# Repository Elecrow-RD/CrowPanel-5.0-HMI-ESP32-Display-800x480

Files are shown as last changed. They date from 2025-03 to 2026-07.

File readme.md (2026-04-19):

### 1, Product picture

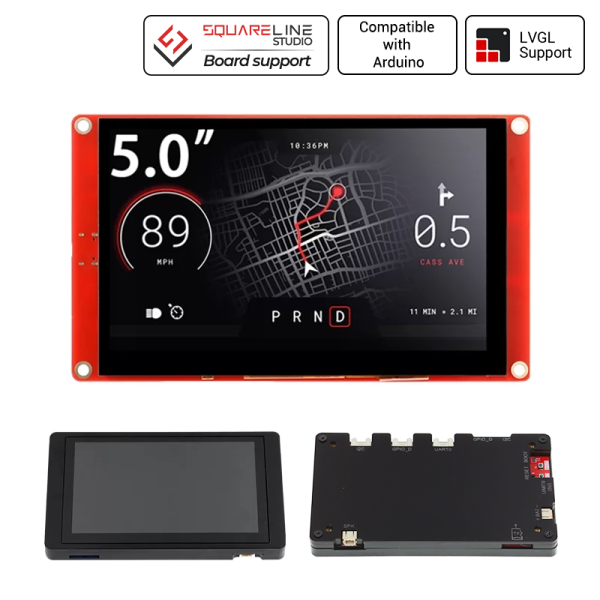
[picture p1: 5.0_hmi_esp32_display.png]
5.0_hmi_esp32_display


### 2, Product version number

| | Hardware | Software | Remark |
| ---- | --- | --- | --- |
| 1 | V1.0 | V1.0 | old |
| 1 | V2.0 | V2.0 | old |
| 1 | V3.0 | V3.0 | latest |

**Version 2.0** adds an automatic download feature over Version 1.0, eliminating the need to press boot+reset again before downloading the program.

**Version 3.0** adds touch timing control based on Version 2.0 to prevent touch failures. When writing programs, you need to build upon the Version 2.0 program to implement the timing control logic.

   PCA9557 Out;
  
   Out.reset();
  
  Out.setMode(IO_OUTPUT);  
  
  Out.setState(IO0, IO_LOW);
  
  Out.setState(IO1, IO_LOW);
  
  delay(20);
  
  Out.setState(IO0, IO_HIGH);
  
  delay(100);
  
  Out.setMode(IO1, IO_INPUT);

### 3, product information

- Model: 5.0 inch CrowPanel ESP32 display
- Main Processor: ESP32-S3-WROOM-1-N4R8
- Resolution: 800*480
- Touch Type: CapacitiveTouch Screen
- Display Type: TN Panel
- Screen: TFT-LCD Screen
- Display driver: ILI6122 & ILI5960
- External power supply: DC5V-2A
- Interface: 2\*UART0,2\*GPIO,2\*I2C,1\*Battery
- Button: BOOT Button and Reset Button
- Active Area: 108\*64.8mm(W\*H)
- Working Temperature: -20℃～70℃
- Storage Temperature: -30℃～80℃

### 4, Use the driver module

| Name | dependency library |
| ---- | --- |
| LVGL | lvgl/lvgl@8.3.3 |

### 5,Quick Start

##### Arduino IDE starts

1.Download the library files used by this product to the 'libraries' folder.

C:\Users\Documents\Arduino\libraries\



2.Open the Arduino IDE

arduino1

3.Open the code configuration environment and burn it



##### ESP-IDF starts

1.Right-click on an empty space in the project folder and select "Open with VS Code" to open the project.



2.In the IDF plug-in, select the port, then compile and flash



##### PlatformIO starts

1.Right-click on an empty space in the project folder and select "Open with VS Code" to open the project.



2.In the PlatformIO plug-in, select the port, then compile and flash

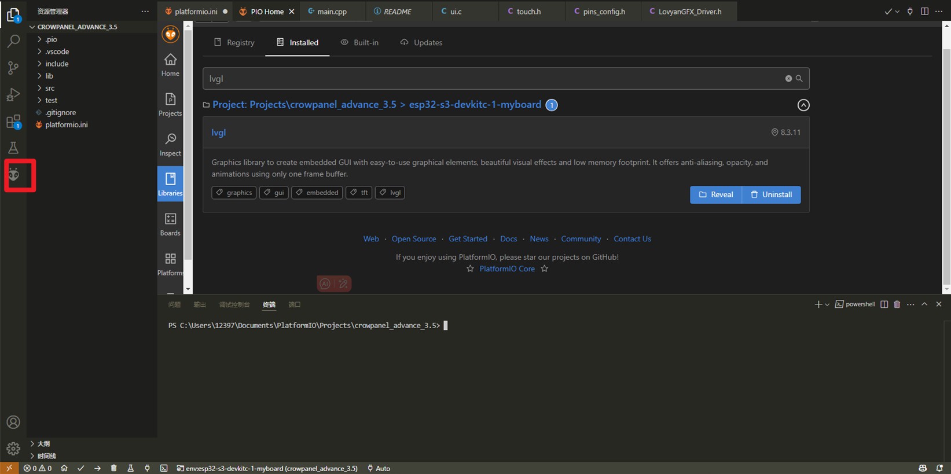
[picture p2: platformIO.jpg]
platformIO


##### Micropython starts

1,Right-click on an empty space in the project folder and select "Thonny" to open the project.

thonny

2,In thonny software, select the master and port, then run the program

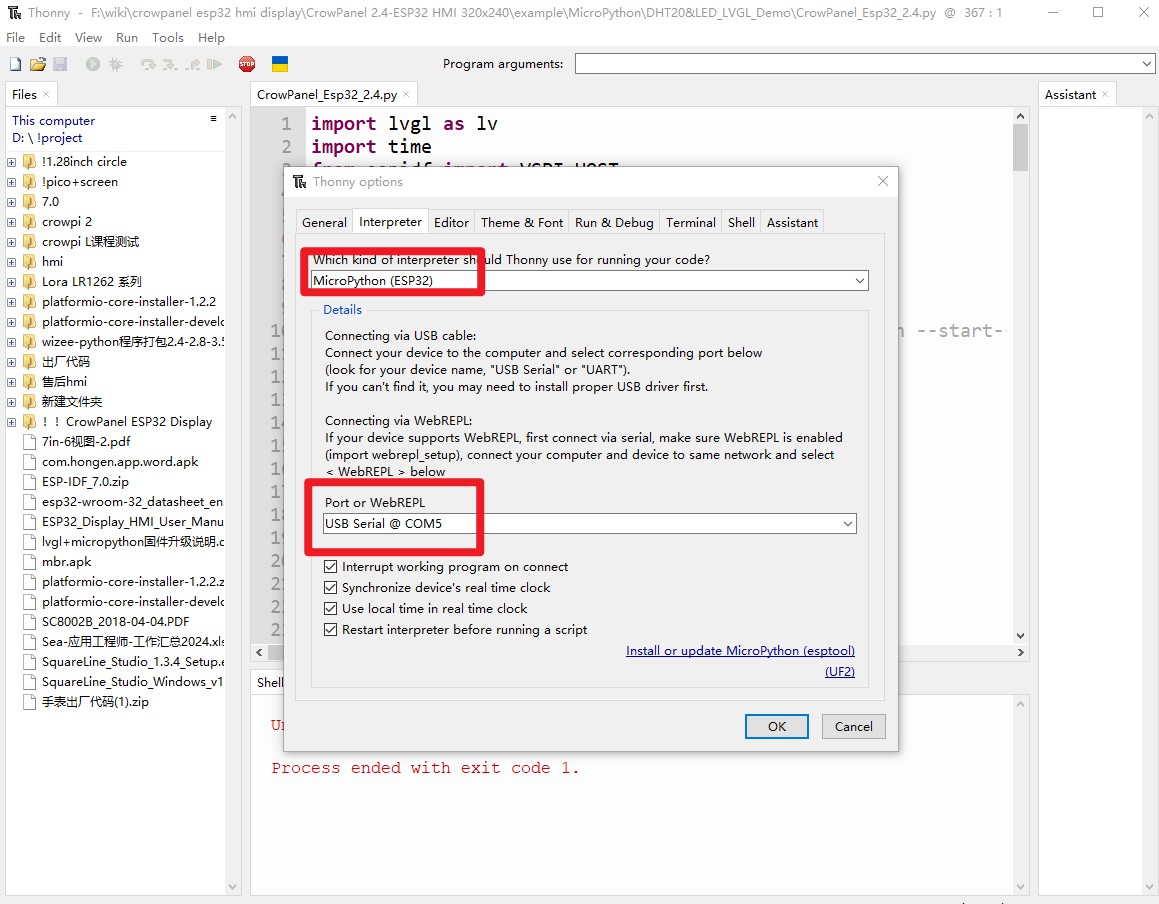
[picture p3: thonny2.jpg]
thonny2


### 6,Folder structure.

|--3D file： Contains 3D model files (.stp) for the hardware. These files can be used for visualization, enclosure design, or integration into CAD software.

|--Datasheet: Includes datasheets for components used in the project, providing detailed specifications, electrical characteristics, and pin configurations.

|--Eagle_SCH&PCB: Contains **Eagle CAD** schematic (`.sch`) and PCB layout (`.brd`) files. These are used for circuit design and PCB manufacturing.

|--example: Provides example code and projects to demonstrate how to use the hardware and libraries. These examples help users get started quickly.

|--factory_firmware: Stores pre-compiled factory firmware that can be directly flashed onto the device. This ensures the device runs the default functionality.

|--factory_sourcecode: Contains the source code for the factory firmware, allowing users to modify and rebuild the firmware as needed.

### 7,Pin definition

class LGFX : public lgfx::LGFX_Device
{
public:

  lgfx::Bus_RGB     _bus_instance;
  lgfx::Panel_RGB   _panel_instance;

  LGFX(void)
  {

    {
      auto cfg = _bus_instance.config();
      cfg.panel = &_panel_instance;
    
      cfg.pin_d0  = GPIO_NUM_8; // B0
      cfg.pin_d1  = GPIO_NUM_3;  // B1
      cfg.pin_d2  = GPIO_NUM_46;  // B2
      cfg.pin_d3  = GPIO_NUM_9;  // B3
      cfg.pin_d4  = GPIO_NUM_1;  // B4
    
      cfg.pin_d5  = GPIO_NUM_5;  // G0
      cfg.pin_d6  = GPIO_NUM_6; // G1
      cfg.pin_d7  = GPIO_NUM_7;  // G2
      cfg.pin_d8  = GPIO_NUM_15;  // G3
      cfg.pin_d9  = GPIO_NUM_16; // G4
      cfg.pin_d10 = GPIO_NUM_4;  // G5
    
      cfg.pin_d11 = GPIO_NUM_45; // R0
      cfg.pin_d12 = GPIO_NUM_48; // R1
      cfg.pin_d13 = GPIO_NUM_47; // R2
      cfg.pin_d14 = GPIO_NUM_21; // R3
      cfg.pin_d15 = GPIO_NUM_14; // R4
    
      cfg.pin_henable = GPIO_NUM_40;
      cfg.pin_vsync   = GPIO_NUM_41;
      cfg.pin_hsync   = GPIO_NUM_39;
      cfg.pin_pclk    = GPIO_NUM_0;
      cfg.freq_write  = 15000000;
    
      cfg.hsync_polarity    = 0;
      cfg.hsync_front_porch = 8;
      cfg.hsync_pulse_width = 4;
      cfg.hsync_back_porch  = 43;
    
      cfg.vsync_polarity    = 0;
      cfg.vsync_front_porch = 8;
      cfg.vsync_pulse_width = 4;
      cfg.vsync_back_porch  = 12;
    
      cfg.pclk_active_neg   = 1;
      cfg.de_idle_high      = 0;
      cfg.pclk_idle_high    = 0;
    
      _bus_instance.config(cfg);
    }
            {
      auto cfg = _panel_instance.config();
      cfg.memory_width  = 800;
      cfg.memory_height = 480;
      cfg.panel_width  = 800;
      cfg.panel_height = 480;
      cfg.offset_x = 0;
      cfg.offset_y = 0;
      _panel_instance.config(cfg);
    }
    _panel_instance.setBus(&_bus_instance);
    setPanel(&_panel_instance);

  }
};

\#define TOUCH_GT911_SCL 20//20 

#define TOUCH_GT911_SDA 19//19

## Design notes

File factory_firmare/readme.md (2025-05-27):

# How to install the factory demo firmware with flash download tool?

#### 1.Preparation:

- USB C cable
- Laptop/PC
- Crowpanel Advance HMI ESP32 AI Display
- Flash download tool

Check whether the materials on the PCBA board are defective. Such as less material, false welding, tin and other bad phenomena.

#### 2.Flash the firmware 

##### Step1 Connect the ESP32 display to the laptop/PC with USB-C cable. The power indicator will light up.

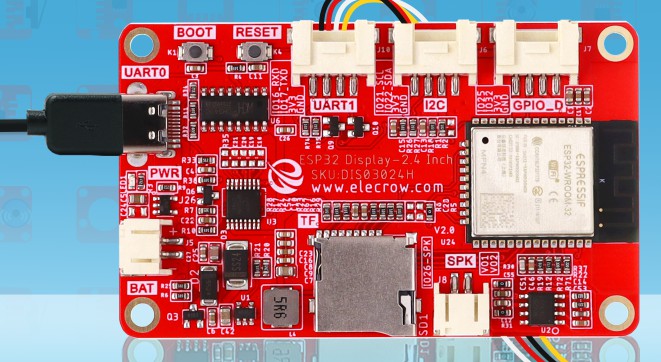
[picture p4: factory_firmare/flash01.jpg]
flash01


##### Step2 Open the flash download tool. 

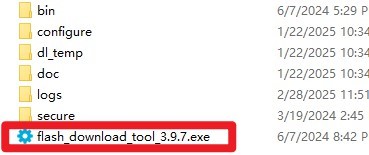
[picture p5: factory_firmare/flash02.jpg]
flash02


For the  Crowpanel Advance HMI ESP32 AI Display, the chip select ESP32-S3:

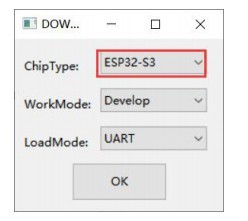
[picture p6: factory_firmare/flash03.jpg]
flash03


##### Step3

①Choose the firmware files;

flash0

②Enter the address: 

boot_app0.bin------0xe000

xxxx.ino.bin--------0x10000

xxxx.ino.bootloader.bin------0x0

xxxx.ino.partitions.bin-------0x8000

③Check the firmware files;

④Select the correct port number;

⑤Click “Start” to download

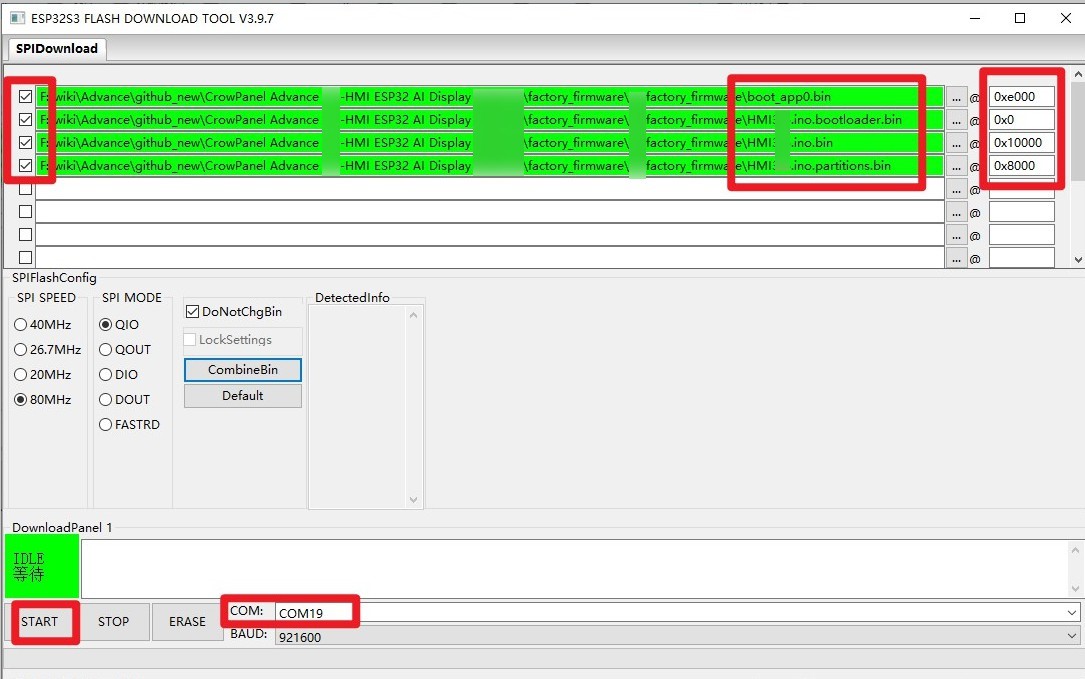
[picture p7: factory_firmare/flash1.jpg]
flash1


### Note: If it is v1.0 version, before downloading firmware or program, you need to press the boot button, then short press the reset button, and then release the boot button to enter the burn mode. If it is v2.0 or above, this step is not needed, it will automatically enter into burn mode.

##### Step5 After the download is complete, blue FINISH will be displayed, and the progress bar at the bottom shows that it has come to an end.

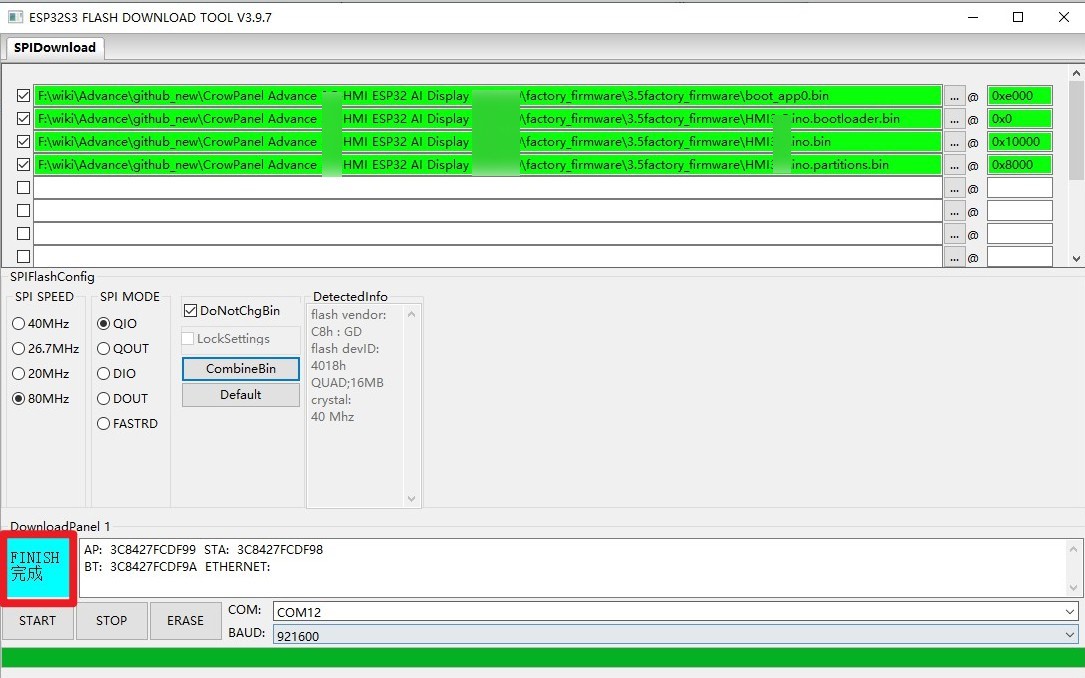
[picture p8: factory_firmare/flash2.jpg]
flash2


##### Step6 Press the reset button to show the demo.

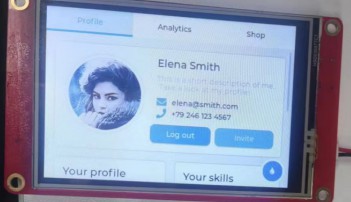
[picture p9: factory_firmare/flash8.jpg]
flash8


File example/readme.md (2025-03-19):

**Arduino**: This folder contains sample programs for the Arduino platform, which is known for its ease of use and versatility in creating interactive electronic projects.

#### NOTE!!!:When running this program , you need to download the officially provided libraries and place them in the libraries of arduino. esp32 version needs to be 2.0.14/2.0.15. the version of the libraries is the same as the officially provided version.

Link to the corresponding course wiki:https://www.elecrow.com/wiki/ESP32_Display_5.0-inch_HMI_Arduino_Tutorial.html

Video Tutorial Links：https://www.youtube.com/watch?v=x4LrIeEJTls&t=2s

**ESP_IDF**: This directory holds example code for the Espressif IoT Development Framework (ESP-IDF), designed for developing applications on ESP32 and ESP8266 microcontrollers.

Link to the corresponding course wiki:https://www.elecrow.com/wiki/CrowPanel-ESP32-5.0-inch-with-ESP-IDF.html

**Esphome**: Here you'll find sample programs for Esphome, a firmware framework that simplifies the process of creating smart home devices using ESP8266/ESP32 chips.

Link to the corresponding course wiki:https://www.elecrow.com/wiki/CrowPanel_ESP32_5.0-inch_with_ESPHome.html

**MicroPython**: This section includes examples for MicroPython, a lean and efficient implementation of the Python programming language that can run on microcontrollers.

Link to the corresponding course wiki:https://www.elecrow.com/wiki/5.0-inch_ESP32_Display_MicroPython_Tutorial.html

**PlatformIO**: This folder contains sample projects for PlatformIO, an open-source ecosystem that streamlines the development process across various embedded platforms by providing a consistent environment for coding, compiling, and uploading firmware.:

Link to the corresponding course wiki:https://www.elecrow.com/wiki/5-inch-esp32-dispaly-platformio-tutorial.html

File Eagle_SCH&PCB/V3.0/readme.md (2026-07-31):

# CrowPanel ESP32 Display 5.0-inch V3.0 Product Hardware Driver Guide

| Item | Details |
|---|---|
| Document Version | V1.0 |
| Date | 2026-07-29 |
| Author | OpenAI Codex (compiled from project materials) |
| Applicable Hardware | CrowPanel ESP32 Display 5.0-inch V3.0 |
| Schematic Baseline | `V3.0/CrowPanel ESP32 Display-5.0-inch-V3.0-20240314 .sch/.pdf` |
| Driver Baseline | Board-level examples under `Arduino/Course` and libraries included with the repository |

## 1. Document Purpose and Determination Rules

This document is intended for hardware maintenance, Arduino/ESP-IDF driver porting, and onboarding handoffs. Cross-validation follows this priority order:

1. Configurations actually used in board-level examples (highest priority; referred to in this document as “code evidence”).
2. Schematic net names, component connections, and PCB materials (referred to in this document as “schematic evidence”).
3. Default values and comments in the driver libraries included with the repository (for reference only; disregarded when they conflict with board-level code).

The project does not include test reports, firmware version tags, or experimental records. Therefore, “verified” means only that the configuration is used by the board-level course examples provided in the repository. Examples included with third-party libraries are not considered validation evidence for this board. Near line 8308 of the schematic source file, there is an unclosed multiline `<text>` tag, preventing strict XML parsers from loading the file completely. This document cross-checks the information through visual review of the EAGLE PDF and text-based net extraction. Repairing the source file is recommended.

Validation levels: **A** = board-level code matches the schematic; **B** = supported only by board-level code or expansion-module examples; **C** = supported only by the schematic, with no software operation; **D** = discrepancies exist and must be handled according to the notes.

## 2. Product Peripheral Overview

| Category | Device/Module | Primary Interfaces and Pins | Validation | Software Layer/Status |
|---|---|---|---|---|
| MCU | ESP32-S3-WROOM-1-N4R8 | 4 MB Flash, 8 MB PSRAM; onboard GPIOs | A | Arduino-ESP32; uses ESP-IDF drivers at the lower level |
| Wireless | ESP32-S3 2.4 GHz Wi-Fi / BLE | Internal module RF, no external GPIO | B | `WiFi.h`, classic Arduino ESP32 BLE library |
| Display | 800×480 RGB565 LCD | D0..D15=`8,3,46,9,1,5,6,7,15,16,4,45,48,47,21,14`; DE40, VSYNC41, HSYNC39, PCLK0 | A | LovyanGFX 1.2.21 + LVGL 9.1.0 |
| Backlight | MT9201 boost converter and LED string | EN=GPIO2, active high | A | Arduino GPIO; PWM dimming can be added |
| Touch | Capacitive touch panel; code uses the GT911 driver | SDA19, SCL20; reset/interrupt routed through PCA9557 | D | TAMC_GT911 1.0.2, currently polled |
| I/O Expansion | PCA9557PW | I2C GPIO19/20, runtime address `0x18`; IO0=TP_RESET, IO1=TP_INT | D | Repository PCA9557 1.0.0 |
| Audio | NS4168 I2S digital power amplifier + 2-pin speaker connector | DOUT17, LRCLK18, BCLK42 | A | ESP-IDF legacy `driver/i2s.h` |
| Storage | MicroSD/TF card slot | CS10, MOSI11, SCK12, MISO13 | A | Arduino `SPI` + `SD`/`FS` |
| Indicator/Expansion | Red LED, D connector | GPIO38, push-pull output; both HIGH and LOW are used by examples | A | Arduino GPIO; signal is also broken out |
| Debugging/Flashing | USB-C + CH340C | USB D+/D-; UART0 TX/RX; DTR/RTS automatic flashing | C | Host CH340 driver + UART0; example serial monitor at 115200 |
| Buttons | BOOT, RESET | BOOT→GPIO0, active low; RESET→EN, active low | A/C | Hardware buttons; GPIO0 is also LCD PCLK |
| Expansion UART | UART0 4-pin connector; GPS example uses UART1 | UART0 is module TXD0/RXD0; GPS code uses RX44/TX43, 9600 8N1 | B/C | `HardwareSerial` |
| Expansion I2C | Crowtail I2C / pin header | SDA19, SCL20, 3.3 V, GND | A | Shared bus with touch, PCA9557, and DHT20 |
| External Sensor | DHT20 (course demonstration, not an onboard device) | I2C GPIO19/20, address `0x38` | B | `Crowbits_DHT20` |
| External GPS | NMEA GPS (course demonstration, not an onboard device) | UART1 RX44/TX43, 9600 8N1 | B | `HardwareSerial(1)`, software NMEA parsing |
| Power | USB 5 V, lithium battery, HM3416B 3.3 V DC/DC | 3.3 V formula labeled as `0.6*(R20/R21+1)` | C | Hardware only; no software PMIC interface |
| Charging | 4054A single-cell lithium battery charger | USB VBUS→charger→BAT+, schematic labeled 500 mA | C | Hardware only; no battery-level or charging-status driver |
| LCD Power Switch | PMOS/NPN load switch | Controlled by ESP32_RESET/peripheral gating, TFT-3V3 | C | Hardware sequencing; no independent GPIO API |

## 3. Global Pin and Resource Matrix

| GPIO | Current Function | Direction/Multiplexing | Sharing or Restrictions |
|---:|---|---|---|
| 0 | LCD PCLK; BOOT button | RGB clock output; boot strapping input | **High risk**: pulling low during reset enters download mode |
| 1 | LCD B7 | RGB data output | Used by LCD |
| 2 | LCD backlight enable | Push-pull output, active high; PWM-capable | Set high only after display startup completes |
| 3 | LCD B4 | RGB data output | Used by LCD |
| 4 | LCD G7 | RGB data output | Used by LCD |
| 5/6/7 | LCD G2/G3/G4 | RGB data output | Used by LCD |
| 8/9 | LCD B3/B6 | RGB data output | Used by LCD |
| 10 | TF CS | SPI chip-select output, active low | Dedicated to card slot |
| 11 | TF MOSI | SPI controller-out, peripheral-in | Schematic net name still retains the legacy-compatible `TP_DIN` label |
| 12 | TF SCK | SPI clock | Schematic net name still retains the legacy-compatible `TP_CLK` label |
| 13 | TF MISO | SPI controller-in, peripheral-out | Schematic net name still retains the legacy-compatible `TP_OUT` label |
| 14 | LCD R7 | RGB data output | Used by LCD |
| 15/16 | LCD G5/G6 | RGB data output | Used by LCD |
| 17 | I2S SDOUT | I2S TX data output | NS4168 |
| 18 | I2S LRCLK/WS | I2S TX clock output | NS4168 |
| 19 | I2C SDA | Open-drain, bidirectional | Shared by GT911, PCA9557, DHT20, and expansion connector |
| 20 | I2C SCL | Open-drain output | Same as above; onboard 4.7 kΩ pull-up |
| 21 | LCD R6 | RGB data output | Used by LCD |
| 38 | Red LED / D connector / pin header | Configured by examples as push-pull output | **High risk**: peripherals must not contend with the LED driver |
| 39/40/41 | LCD HSYNC/DE/VSYNC | RGB timing outputs | Used by LCD |
| 42 | I2S BCLK | I2S TX clock output | NS4168 |
| 43/44 | GPS TX/RX (code) | UART1, 9600 8N1 | No naming/connection evidence for these pins in the schematic; treat them as expansion wiring |
| 45/47/48 | LCD R3/R5/R4 | RGB data output | Used by LCD; GPIO45 is also an ESP32-S3 strapping pin and must not be externally pulled during startup |
| 46 | LCD B5 | RGB data output | ESP32-S3 input restrictions/strapping properties must be reviewed when revising the board; currently used by the RGB code |

## 4. Startup and Common Initialization Sequence

Retaining the sequence proven by the working LVGL example is recommended:

1. Call `Serial.begin(115200)` and initialize I2C with `Wire.begin(19, 20)`.
2. Configure all PCA9557 pins as outputs; drive IO0/IO1 low for 20 ms; drive IO0 high and wait 100 ms; then configure IO1 as an input.
3. Initialize other peripherals on the same bus (DHT20 in the example), configure GPIO38 as an output, and initially drive it low.
4. Call `lcd.begin()`; if it fails, first verify that PSRAM is set to **OPI PSRAM** under Arduino Tools.
5. Wait 200 ms and initialize LVGL; then wait another 100 ms and initialize touch.
6. Register the two full-screen buffers and the input device, then finally drive GPIO2 high to enable the backlight.

Critical sequence:

```cpp
Wire.begin(19, 20);
Out.reset();
Out.setMode(IO_OUTPUT);
Out.setState(IO0, IO_LOW); Out.setState(IO1, IO_LOW);
delay(20);
Out.setState(IO0, IO_HIGH);
delay(100);
Out.setMode(IO1, IO_INPUT);
```

This sequence prevents the screen from displaying uninitialized frames at power-on and completes the touch reset/interrupt pin direction transition. Do not remove these delays without understanding the panel’s power-on requirements.

## 5. Detailed Peripheral Driver Guide

### 5.1 ESP32-S3-WROOM-1-N4R8 MCU

- **Hardware**: The schematic explicitly identifies the module as ESP32-S3-WROOM-1-N4R8, meaning 4 MB of module Flash and 8 MB of PSRAM. The board-level display implementation uses two 800×480×16-bit full-screen buffers, requiring approximately 1.536 MB, so PSRAM must be enabled.
- **Driver method**: Arduino-ESP32 framework; the display and I2S use ESP-IDF peripheral drivers at the lower level; task scheduling is provided by the Arduino/FreeRTOS environment, and the code performs no direct register operations.
- **Boot pins**: EN is an active-low reset; GPIO0 low selects download mode, while GPIO0 high boots from Flash. CH340C DTR/RTS signals implement automatic flashing through transistors.
- **Key configuration**: All course examples configure the debug serial port at 115200. The repository does not provide a `platformio.ini`, Arduino FQBN, or Arduino-ESP32 core version. The build environment must therefore be pinned and regression-tested before porting.

### 5.2 800×480 RGB LCD and LVGL

- **Electrical/multiplexing**: 16-bit parallel RGB565. LovyanGFX `pin_data[0..15]` matches the schematic order of B3..B7, G2..G7, and R3..R7.
- **Timing**: PCLK 12 MHz; HSYNC/VSYNC active low; H front/pulse/back=`8/4/43`; V front/pulse/back=`8/4/12`; data is valid on the falling edge of PCLK; DE idle low and PCLK idle low.
- **Geometry/buffering**: 800×480, LVGL `RGB565`, two full-screen LovyanGFX framebuffers, `LV_DISPLAY_RENDER_MODE_FULL`, with buffers swapped at VSYNC.
- **Dependencies**: LovyanGFX 1.2.21, LVGL 9.1.0, and Arduino-ESP32 RGB LCD/PSRAM support.

```cpp
const int8_t rgb[16] = {8,3,46,9,1,5,6,7,15,16,4,45,48,47,21,14};
// DE=40, VSYNC=41, HSYNC=39, PCLK=0
busConfig.freq_write = 12000000;
busConfig.pclk_active_neg = 1;
```

- **Caution**: GPIO0 serves as both PCLK and BOOT. The LCD/ribbon cable must not pull it low during the reset sampling period. If flashing fails or the board repeatedly enters download mode, inspect this net first.

### 5.3 LCD Backlight and Display Power

- **Backlight**: GPIO2 connects to the MT9201 EN pin. The examples use push-pull HIGH to turn the backlight on and LOW to turn it off. The MT9201 boosts the backlight anode supply, while the cathode is connected through the feedback-resistor loop; the GPIO does not directly carry LED current.
- **Power-on strategy**: Drive GPIO2 high only after LCD, LVGL, and touch initialization is complete.
- **Dimming**: The current code supports only on/off control. If LEDC PWM is added, confirm the PWM frequency range supported by the MT9201 EN input; the repository does not provide this parameter, so it must not be assumed.
- **Panel 3.3 V**: TFT-3V3 is gated by a PMOS/NPN circuit associated with `ESP32_RESET` and has no independent software-control pin. During maintenance, do not incorrectly document it as a GPIO-controlled power supply.

### 5.4 GT911 Capacitive Touch and PCA9557

- **Bus**: I2C SDA=GPIO19 and SCL=GPIO20, open-drain, with 4.7 kΩ schematic pull-ups to 3.3 V. The code does not explicitly specify a frequency and therefore uses the Arduino `Wire` default frequency, whose exact value depends on the core version. When porting, explicitly setting the frequency and validating from 100 kHz is recommended.
- **GT911 address**: The driver’s `begin()` defaults to `0x5D` and also supports `0x14`; the board-level code does not override the address. The current implementation should use `0x5D`.
- **Reset/interrupt**: The ESP32 does not connect directly to GT911 RST/INT. The schematic shows PCA9557 IO0→`TP-RESET` and IO1→`INTE`. At power-on, the code uses IO0 to generate a 20 ms low/100 ms high reset sequence and then switches IO1 back to input mode.
- **Read method**: `TOUCH_GT911_INT=-1` and `RST=-1`; TAMC_GT911 may still attempt GPIO operations on negative pin values. Reliable reset is actually provided by PCA9557. The application always returns `touch_has_signal()=true` and polls `ts.read()` without an MCU GPIO interrupt.
- **Coordinates**: The raw range is 800×480 with `ROTATION_NORMAL`. X and Y are both mapped from 800/480 to 0, reversing both axes to match the screen orientation.
- **PCA9557 address discrepancy**: The actual library constant is `DEV_ADDR=0x18`, and the board-level code runs with this value. A large block of historical comments in the same header still identifies the standard address as `0x41`, while the schematic text also contains `PCA9557pw-118`. **Porting must use `0x18` and confirm the physical device with an I2C scan; do not copy 0x41.**
- **PCA9557 registers**: `0x00` input, `0x01` output, `0x02` polarity, and `0x03` configuration; configuration bit 0=output, 1=input.

### 5.5 NS4168 I2S Audio

- **Connections**: GPIO17→SDATA, GPIO42→BCLK, and GPIO18→LRCLK; the NS4168 differential power output connects to the J5 speaker connector. The schematic configures `CTRL` through a 100 kΩ hardware connection, with no MCU control pin.
- **Mode**: I2S0, controller transmit, standard I2S, 44.1 kHz, 16-bit, stereo `RIGHT_LEFT`; the example writes the same sample to both channels, and the amplifier outputs according to its hardware mode.
- **DMA/interrupt**: Interrupt level 1, DMA buffers of 8×64 frames, APLL disabled, automatic clearing of TX descriptors, and no MCLK.
- **Dependency**: The legacy ESP-IDF `driver/i2s.h` included with Arduino-ESP32. If a newer ESP-IDF removes the legacy API, migrate to the `i2s_std` channel API while preserving the same wire format.

```cpp
i2s_driver_install(I2S_NUM_0, &cfg, 0, nullptr);
i2s_set_pin(I2S_NUM_0, &pins); // BCLK42, WS18, DOUT17
i2s_set_clk(I2S_NUM_0, 44100, I2S_BITS_PER_SAMPLE_16BIT, I2S_CHANNEL_STEREO);
```

- **Risk**: The example amplitude is 32767 (full scale), producing a high startup volume. Production firmware should implement digital limiting, fade-in/fade-out, and silent frames to prevent popping and speaker overload.

### 5.6 MicroSD/TF Storage

- **Connections**: CS=GPIO10, MOSI=11, SCK=12, and MISO=13; operating level is 3.3 V. DATA1/DATA2 are not used for 4-bit SDIO.
- **Mode**: Arduino SPI controller; after `SPI.begin(12,13,11)`, wait 100 ms and then mount with `SD.begin(10)`. No frequency is passed, so the library’s default SD SPI frequency is used. If trace quality or card compatibility is poor, initialization should explicitly start at a low frequency before increasing it.
- **Dependencies**: `SPI.h`, `SD.h`, and `FS.h`.
- **Legacy labels**: The schematic nets also carry `TP_CLK/TP_DIN/TP_OUT`, but the working touch implementation on this V3.0 board is the GPIO19/20 GT911. Pins 11/12/13 should be used for TF SPI. The XPT2046 configuration in LVGL `touch.h` is only a commented-out cross-board template and does not indicate that it can be used concurrently on this board.

### 5.7 GPIO38 Red LED and D Expansion Connector

- **Connections**: `IO38_D` connects simultaneously to the MCU, red LED branch, J2 D connector signal pin, and J4 pin-header P4.
- **Driver**: The code configures it as a push-pull `OUTPUT` and alternates HIGH/LOW in the examples. The actual LED on/off polarity indicated by the schematic must be confirmed against the physical LED branch transistor/series resistor. Therefore, maintenance interfaces should use “write level” terminology instead of assuming a name such as `HIGH=on`.
- **Conflict**: Devices connected to J2 must not actively drive GPIO38. If it is used as an input, UART, or high-speed signal, the onboard LED load will affect edges/levels. The course schematic text mentions an “expansion UART,” but the current GPS example actually uses pins 43/44 rather than GPIO38.

### 5.8 USB-C, CH340C, UART0, BOOT/RESET

- **USB-C**: USB 2.0 D+/D- connect to the CH340C through 22 Ω series resistors; VBUS also participates in system power and battery charging. This connector is not an ESP32-S3 native USB data port.
- **UART0**: CH340C TX→ESP32 RXD0 and CH340C RX←ESP32 TXD0; the same signal pair is also routed to the J10 UART0 4-pin connector. Course examples default to 115200 as the log baud rate.
- **Automatic flashing**: DTR/RTS control EN and GPIO0 through S9013 transistors. The BOOT button directly pulls GPIO0 low, and the RESET button pulls EN low.
- **Conflict**: External UART devices connected to J10 must use 3.3 V TTL and will be connected in parallel with the CH340C. RS-232 levels and 5 V TTL are prohibited. An external device transmitting may contend with the CH340C TX output.

### 5.9 Wi-Fi and BLE

- **Hardware**: The ESP32-S3-WROOM-1 module includes integrated 2.4 GHz Wi-Fi/BLE RF functionality; no off-module GPIO driver is required.
- **Wi-Fi example**: Station mode using `WiFi.begin(ssid,password)` with automatic reconnection; it blocks while waiting for a connection at 100 ms intervals. Production firmware should add timeouts, secure credential storage, and an offline state machine.
- **BLE example**: Device name `ESP32SPI-BLE`, with custom service/characteristic UUIDs and READ/WRITE/NOTIFY properties. After creating the service, the example starts advertising but does not configure pairing, encryption, MTU, or explicitly restart advertising after disconnection.
- **Dependencies**: Arduino-ESP32 `WiFi.h` and the legacy `BLEDevice` API. Using wireless connectivity together with large double buffers increases pressure on PSRAM and internal DMA-capable memory.

### 5.10 I2C Expansion and DHT20 Example

- **Interface**: J8/pin headers expose 3.3 V, GND, SDA19, and SCL20. These lines are shared with the touch controller and PCA9557, so `Wire.begin()` must not be called again with different pins.
- **DHT20**: The external module’s default address is `0x38`. `begin()` waits 100 ms and sends the `0x71` status command; the measurement command is `AC 33 00`, and the busy bit is checked every 10 ms for up to 10 attempts. The LVGL example reads temperature and humidity every 1 s.
- **Caution**: The DHT20 is not included in the schematic BOM; it is only an expansion-connector component validated by the course example. Before adding devices to the bus, check for address conflicts, effective pull-up resistance, and cable length.

### 5.11 GPS/UART1 Expansion Example

- **Wiring**: The code uses `HardwareSerial(1)` with ESP32 RX=GPIO44, TX=GPIO43, 9600 baud, and 8N1. This connection is not present among the named schematic nets and is an example using external jumper wiring/an expansion module.
- **Protocol**: The loop collects NMEA lines and parses positioning fields; no hardware flow control is used.
- **Risk**: TX→RX must be cross-connected, and signal levels are limited to 3.3 V TTL. Do not connect the GPS to CH340/UART0 merely because the schematic includes a “UART0 connector,” as doing so would contend with flashing and logging.

### 5.12 Power, Charging, and Hardware Power Management

- **System 3.3 V**: HM3416B switching regulator; the schematic specifies `Vout=0.6*(R20/R21+1)=3.3V`. There is no software enable interface; 3.3 V powers the MCU and digital peripherals.
- **Battery**: J1 is the single-cell lithium battery connector. BAT+ participates in power delivery through a PMOS/Schottky path. The schematic does not provide a battery ADC divider or fuel gauge, so software cannot read the battery level.
- **Charging**: The 4054A charges the battery from USB VBUS, with the schematic labeling the current as 500 mA. There is no MCU charging-status net. Before replacing the battery, verify the permitted charging current, polarity, and protection board.
- **Backlight power**: The MT9201 boost converter is controlled by GPIO2 EN and is the primary high-power load that can be managed by software.
- **Speaker power**: NS4168 VDD is supplied through the hardware power path, with no independent mute/shutdown GPIO. Low-power designs must evaluate a hardware revision or an I2S mute strategy.

## 6.Schematic and Code Discrepancy List

| Item | Schematic/Library Information | Working Code | Conclusion/Possible Cause |
|---|---|---|---|
| PCA9557 address | Historical library comments specify `0x41`; schematic text shows `PCA9557pw-118` | `DEV_ADDR=0x18` | **Use 0x18**; the library was customized by the board manufacturer, but the documentation was not updated. Scan to confirm after mass production or component substitutions |
| Touch reset/interrupt | Connected to TP_RESET/INTE through PCA9557 IO0/IO1 | The GT911 object is passed `RST=-1, INT=-1`, and the application uses polling | **Follow the board-level combined timing sequence**; PCA9557 handles reset/direction, and the GT911 library’s direct GPIO path cannot be used as-is |
| Touch controller model | The schematic only labels “capacitive touchscreen TP” and does not explicitly identify GT911; a resistive-touch network is also retained | `TOUCH_GT911` is selected | **Use the GT911 code as the reference**; the schematic/template supports multiple display variants, and the BOM/panel part number was not synchronized into the repository |
| Shared TP and TF labels | The GPIO11/12/13 net names include TP_DIN/CLK/OUT | GT911 actually uses I2C 19/20, while SD uses 10–13 | For V3.
0, follow the code assignments; the old net names are legacy labels retained for cross-model compatibility |
| LED polarity | The LED branch exists, but the net names are insufficient to safely determine the user-visible on/off polarity | The example directly uses HIGH/LOW | Define `LED_ON_LEVEL` in the API only after verification on physical hardware; do not infer it solely from the example sequence |
| GPS interface | The schematic explicitly shows a UART0 port and does not identify GPIO43/44 | GPS uses UART1 RX44/TX43 | Treat this as an example of expansion wiring, not as the definition of an onboard interface |
| I2C frequency | The schematic does not specify the protocol frequency | `Wire.begin(19,20)` does not set a frequency | The current implementation relies on the core default; when porting, configure it explicitly and begin validation at 100 kHz |
| SD SPI frequency | The schematic does not specify the protocol frequency | `SD.begin(10)` does not set a frequency | The current implementation relies on the library default; reduce the frequency if high-speed operation is unstable |
| Build versions | No Arduino core/board configuration file is provided | The code specifies OPI PSRAM | This is a handoff gap; a reproducible build manifest must be added |

## 7. Risks and Maintenance Considerations

1. **Boot-strapping pin conflicts**: GPIO0 serves as both LCD PCLK and BOOT, while GPIO45 is used for RGB and is also an ESP32-S3 strapping pin. Power-on sampled levels must be reverified whenever pull-ups, the flex cable, or the panel are changed.
2. **Multiple connections on GPIO38**: The onboard LED, D interface, and pin header share this pin. Bidirectional driving by peripherals can cause contention; it is not a dedicated LED GPIO.
3. **Consolidated I2C bus**: GT911, PCA9557, DHT20, and the expansion port share pins 19/20. A fault can disable both touch and sensors; scanning at startup and reporting `0x18/0x38/0x5D` separately is recommended.
4. **Conflicting PCA9557 address documentation**: Do not use `0x41` from the header comment; use `0x18` from the code and confirm it with an ACK from the physical hardware.
5. **Negative GPIO parameters for touch**: TAMC_GT911’s `reset()` operates on the INT/RST constructor parameters, while the board-level code passes -1. Different Arduino cores handle negative pin numbers differently; a robust port should modify the driver to operate only when the value is `>=0`, or provide a PCA9557 callback.
6. **Large memory and DMA requirements**: Two full-screen RGB565 buffers require approximately 1.536 MB, so OPI PSRAM must be enabled. When Wi-Fi/BLE/audio are enabled simultaneously, monitor the internal DMA heap and PSRAM allocation failures.
7. **Voltage limits**: All GPIO and expansion communications use 3.3 V logic. Do not directly connect 5 V TTL, RS-232, or high-voltage sensors without level shifting.
8. **Audio power**: Full-scale test audio may overload the speaker and cause power-on pops; production firmware requires amplitude limiting and soft mute.
9. **Charging safety**: The schematic specifies 500 mA and provides no software-based temperature or charge-level monitoring. The battery cell must include appropriate protection and support the required charging rate.
10. **No software card detection**: The SD example only uses `SD.cardType()` for detection, and the schematic does not show a separate MCU card-detect net for the socket. For hot swapping, unmount the file system and handle power loss during writes.
11. **Source parseability**: The `.sch` file contains an unclosed text tag, which may cause automated BOM/netlist tools to fail. When maintaining the schematic, repair it in EAGLE first and re-export the PDF/netlist.
12. **Sensitive information**: The Wi-Fi example contains plaintext test SSIDs/passwords. Production firmware and delivery repositories must not retain real credentials.

## 8. Driver Porting Checklist

- [ ] Select the board variant corresponding to ESP32-S3-WROOM-1 N4R8 and verify that 4 MB Flash and 8 MB OPI PSRAM are available.
- [ ] Pin the versions of Arduino-ESP32/ESP-IDF, LovyanGFX 1.2.21, LVGL 9.1.0, TAMC_GT911 1.0.2, and the customized PCA9557 library.
- [ ] Preserve the RGB pin order and the 12 MHz porch/polarity parameters; initialize with a black screen before enabling the GPIO2 backlight.
- [ ] Scan I2C to confirm PCA9557 at `0x18` and GT911 at `0x5D`; when DHT20 is connected, confirm `0x38`.
- [ ] Preserve the 20 ms + 100 ms touch startup timing on PCA9557 IO0/IO1.
- [ ] Verify display, touch, SD, and I2S individually before performing concurrent stress testing.
- [ ] Verify BOOT/RESET/automatic download and UART0 logging, and prevent external devices from contending for UART0 or GPIO38.
- [ ] Test voltage and temperature rise under both USB and battery power, during charging, at peak backlight brightness, and with full-scale audio.
- [ ] Add the actual board package version, build options, production firmware hash, and test records to the release baseline.

## 9. Evidence Index

| Evidence | Location | Purpose |
|---|---|---|
| Schematic PDF/SCH | `V3.0/CrowPanel ESP32 Display-5.0-inch-V3.0-20240314 .pdf/.sch` | Component models, electrical connections, net names, and power architecture |
| Integrated RGB/LVGL/DHT20 example | `Arduino/Course/LVGL_Arduino5.0/LVGL_Arduino5.0.ino` | RGB timing, PCA9557 timing, backlight, buffering, and I2C |
| Board-level touch configuration | `Arduino/Course/LVGL_Arduino5.0/touch.h` | GT911 pins, rotation, polling, and coordinate mapping |
| LED example | `Arduino/Course/Example1_LED_blinking/Example1_LED_blinking.ino` | GPIO38 output verification |
| I2S example | `Arduino/Course/Example2_Play_music/Example2_Play_music.ino` | NS4168 pins, format, sample rate, and DMA |
| TF example | `Arduino/Course/Example3_SD_Card/Example3_SD_Card.ino` | SPI pins and mounting sequence |
| Standalone touch example | `Arduino/Course/Example4_Initialize_the_touch` | Standalone GT911 polling verification |
| BLE/Wi-Fi examples | `Arduino/Course/Example5_BLE`, `Example6_WIFI` | Wireless software interfaces |
| GPS example | `Arduino/Course/Example7_GPS_Module` | UART1 43/44, 9600 8N1 |
| Customized PCA9557 driver | `Arduino/libraries/PCA9557/src/PCA9557.h/.cpp` | Address `0x18`, registers, and read/write flow |
| GT911 driver | `Arduino/libraries/gt911-arduino-main/TAMC_GT911.h/.cpp` | Address, reset, and register access |
| DHT20 driver | `Arduino/libraries/Crowbits_DHT20` | Address, commands, and sampling polling |

## 10. Recommended Follow-Up Engineering Actions

1. Create a unified `board_pins.h`/BSP to eliminate duplicated pin constants across examples that may drift over time.
2. Correct the PCA9557 address comment in the header and add a startup ACK check for `0x18`.
3. Update the GT911 driver’s handling of `-1` pins to explicitly support PCA9557-based reset and polling mode.
4. Add a reproducible build configuration, I2C self-test, PSRAM check, and a concurrent smoke test covering all peripherals.
5. Add the exact part numbers and rated specifications for the panel, touch controller, speaker, and battery to the BOM to resolve the current specification gaps that cannot be verified from the schematic.

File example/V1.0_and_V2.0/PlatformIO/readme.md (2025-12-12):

### Here is a case study of the platformIO platform, for actual use please refer to the wiki link for instructions.
## Complete code link:https://www.elecrow.com/download/product/CrowPanel/ESP32-HMI/5.0-DIS07050H/PIO-Tutorial/CrowPanel_ESP32_5.0-PlatformIO.zip

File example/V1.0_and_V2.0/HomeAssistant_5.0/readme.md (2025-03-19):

# Libraries Overview

## **Adafruit_Sensor-master**
Adafruit Sensor master repository containing various sensor drivers and examples for Arduino.

## **Arduino_GFX**
A library that provides graphical capabilities to Arduino boards, supporting multiple display types.

## **async-mqtt-client-develop**
An asynchronous MQTT client library for embedded systems, allowing non-blocking network communication.

## **AsyncTCP-master**
A lightweight TCP/IP stack for ESP8266/ESP32, enabling asynchronous networking operations.

## **Crowbits_DHT20**
A library for interfacing with DHT20 temperature and humidity sensors using Crowbits modules.

## **DHT-sensor-library-master**
A general-purpose library for reading data from DHT series digital temperature and humidity sensors.

## **FT6236**
A driver library for FT6236 capacitive touchscreen controllers commonly used in touch panels.

## **gt911-arduino**
A library for integrating GT911 capacitive touch screen controller with Arduino platforms.

## **LovyanGFX**
A high-performance graphics library optimized for various displays including TFTs and OLEDs.

## **lvgl**
Light and Versatile Graphics Library (LVGL), an open-source GUI framework suitable for embedded systems.

## **TFT_eSPI**
A library designed for driving ILI9341-based TFT displays via SPI interface on ESP8266 and ESP32.

## **U8g2**
Universal Graphics Library version 2, offering support for monochrome graphic LCDs and OLEDs.

## **UI**
User Interface related files or directories which might contain assets or code snippets for building interfaces.

## **XPT2046_Touchscreen**
A library for handling touch inputs from XPT2046 resistive touchscreen controllers.

## **lv_conf.h**
Configuration header file for LVGL library where users can customize settings such as display resolution, color depth, fonts, themes, widgets, event handlers, memory management

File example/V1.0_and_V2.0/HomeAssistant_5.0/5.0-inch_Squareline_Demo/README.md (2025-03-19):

**If you are using this demo code for the first time, I suggest that you watch this video lesson first.**

video link:

[Design Like a Pro: Create and Export Stunning UI with SquareLine Studio for ESP32 Display](https://www.youtube.com/watch?v=TcWvxw61U_w)

------------------------------------------------------------------------------------------------------------------------------

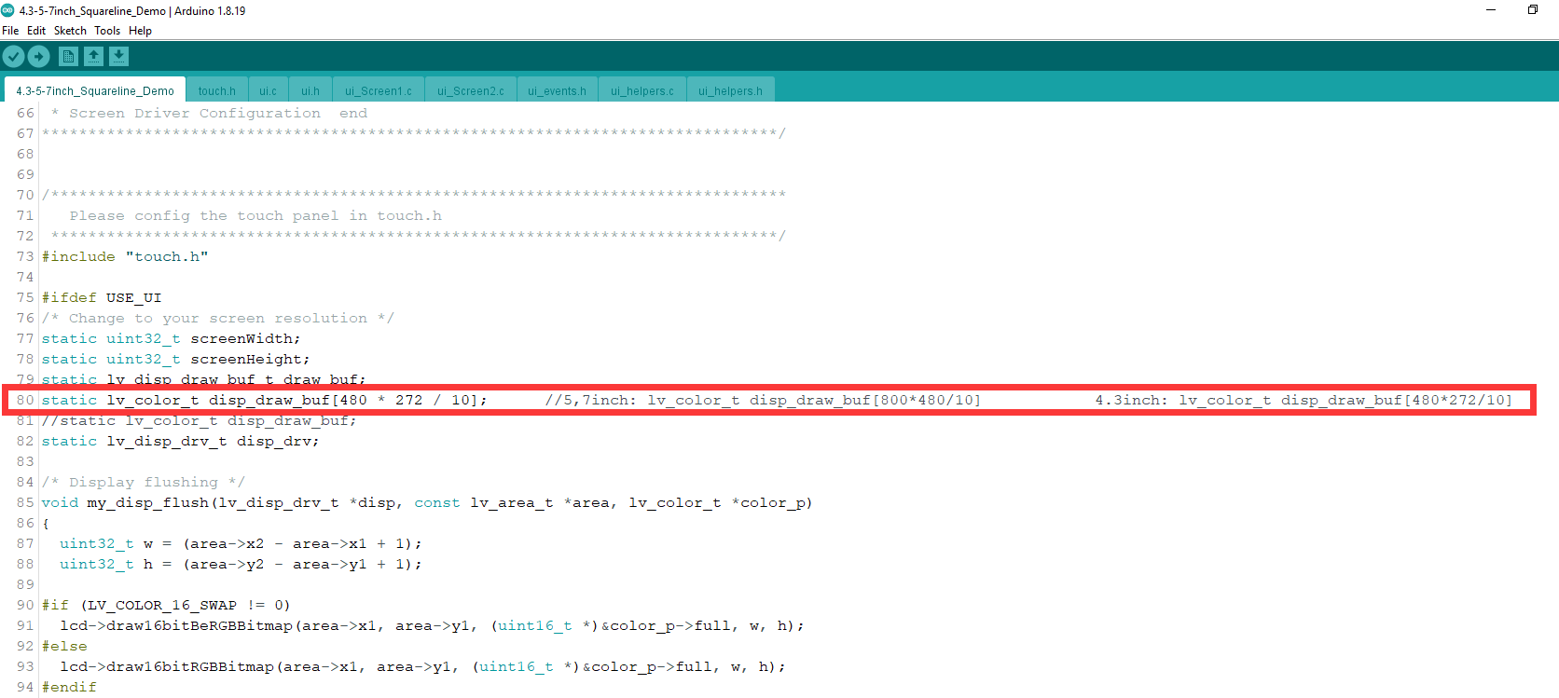
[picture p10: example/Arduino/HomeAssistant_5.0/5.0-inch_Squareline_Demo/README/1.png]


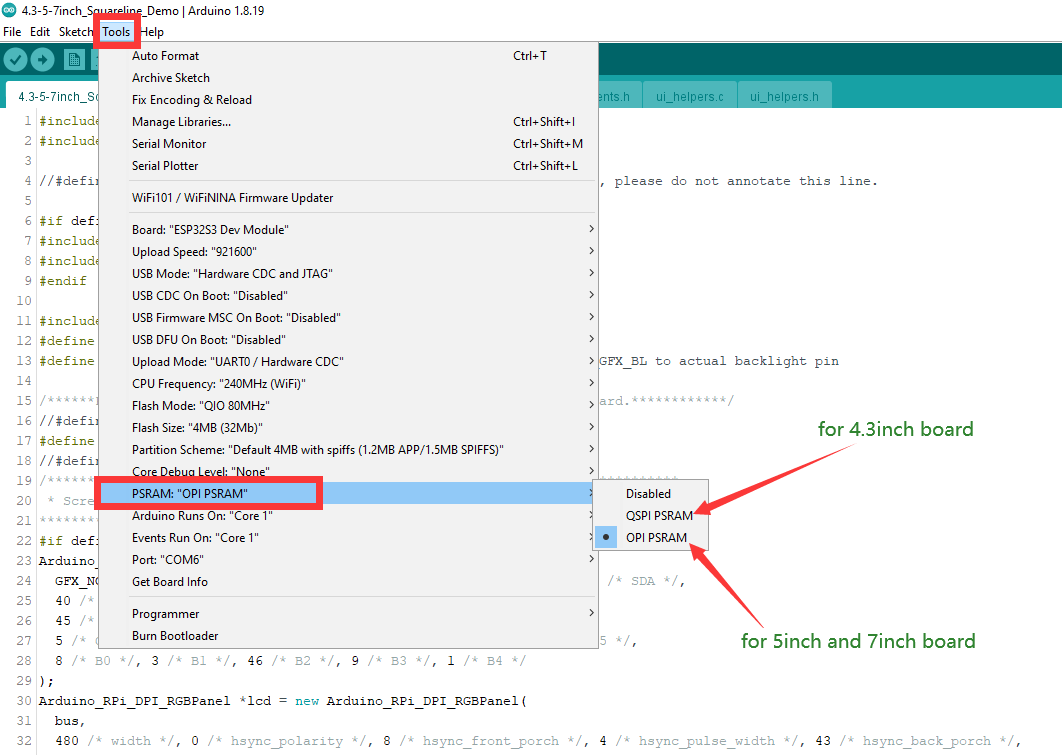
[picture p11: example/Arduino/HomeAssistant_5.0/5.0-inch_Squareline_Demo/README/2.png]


Please notice the tips inside the demo code,that is very important.

**If you don't want to use the UI export from Squareline Studio ,please del the UI file, and open the demo program again, then you can compile the program, or your program may happen some errors.**

--------------------------------------------------------------------------------------------------------------------------

**And if you are using a 4.3-inch board, when configuring the compilation environment, you need to change "PSRAM" to "QSPI PSRAM" to ensure proper display. Go to Tools -> PSRAM -> QSPI PSRAM. For the 5.0-inch and 7.0-inch boards, follow the tutorial and select "OPI PSRAM" as instructed.**



-------------------------------------------------------------END----------------------------------------------------------

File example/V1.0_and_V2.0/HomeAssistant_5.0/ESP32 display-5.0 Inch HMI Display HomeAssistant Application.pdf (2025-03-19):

# Home Assistant Raspberry Pi Server Configuration

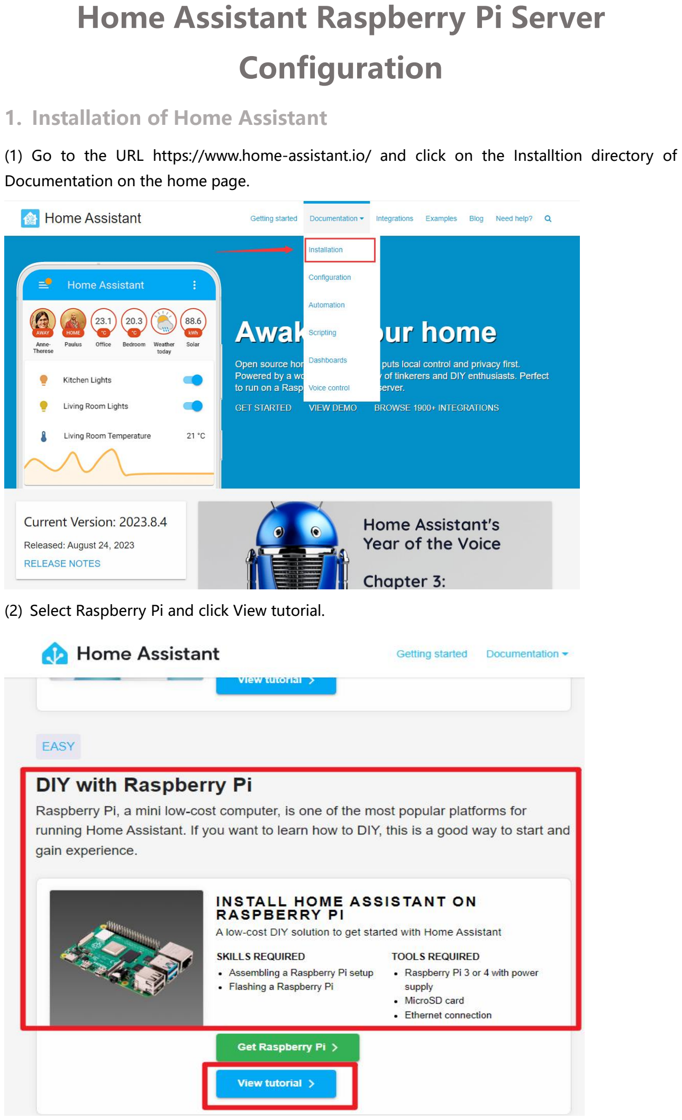
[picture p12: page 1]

## 1. Installation of Home Assistant

(1) Go to the URL https://www.home-assistant.io/ and click on the Installtion directory of Documentation on the home page.
(2) Select Raspberry Pi and click View tutorial.

## 2. Write the image to the SD card

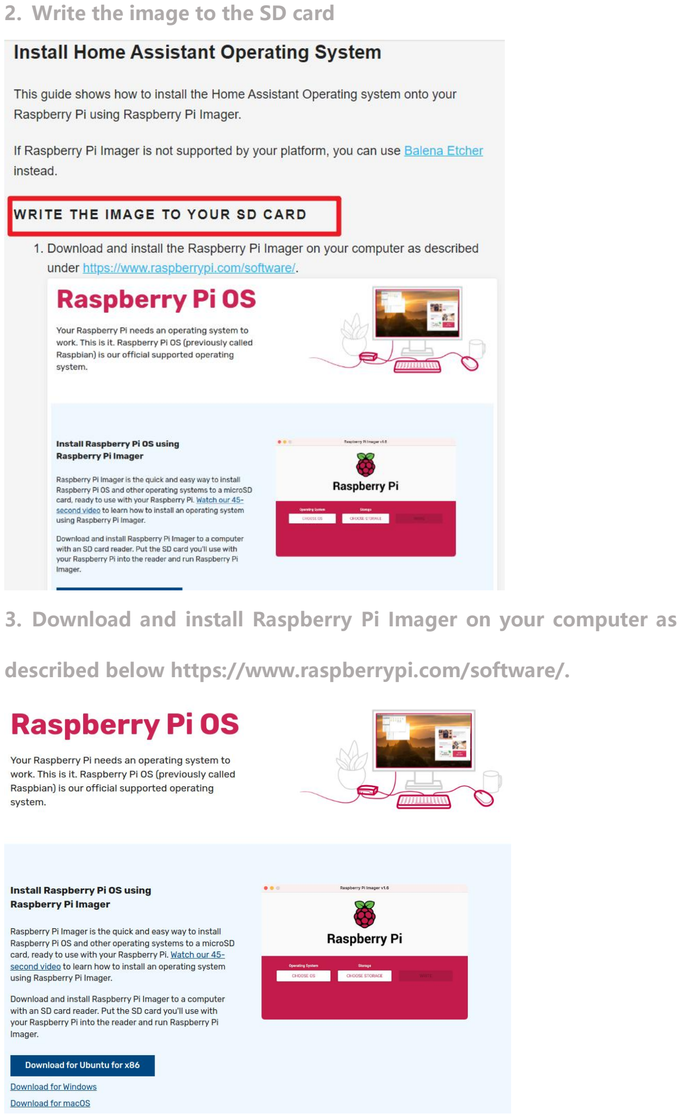
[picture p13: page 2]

## 3. Download and install Raspberry Pi Imager on your computer as

described below https://www.raspberrypi.com/software/.

4. Open Raspberry Pi Imager and select your Raspberry Pi device.

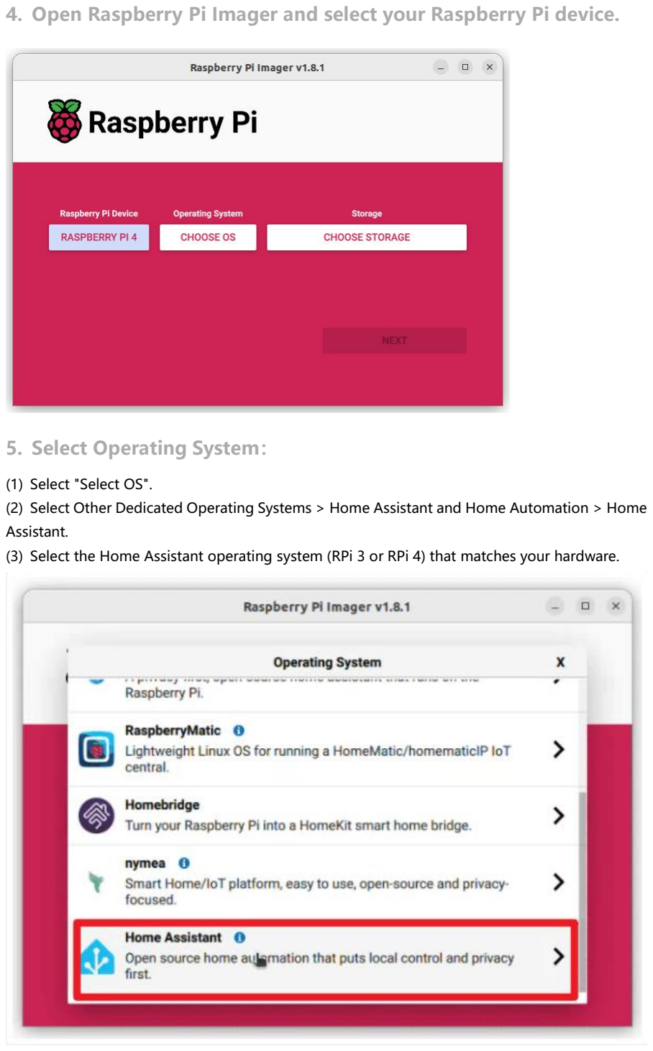
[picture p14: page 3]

## 5. Select Operating System：

(1) Select "Select OS". (2) Select Other Dedicated Operating Systems > Home Assistant and Home Automation > Home

Assistant. (3) Select the Home Assistant operating system (RPi 3 or RPi 4) that matches your hardware.

## 6. Select storage:

(1)Insert the SD card into the computer. Note:The contents of the card will be overwritten. (2)Select your SD card.

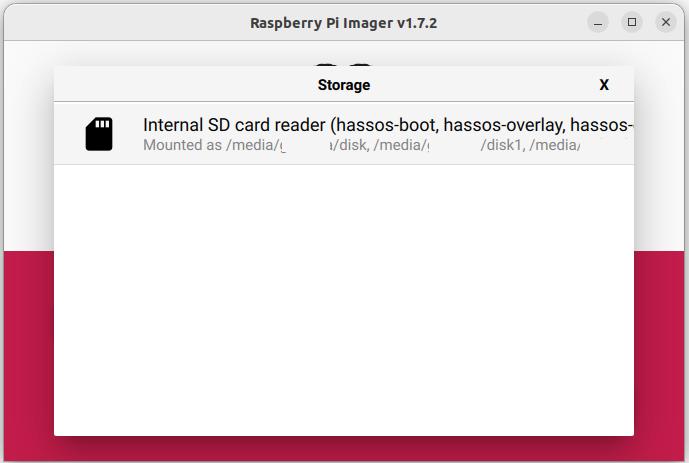
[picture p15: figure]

## 7. Write the installer to the SD card:

(1) To start the process, select Next. (2) Wait for the Home Assistant OS to write to the SD card.

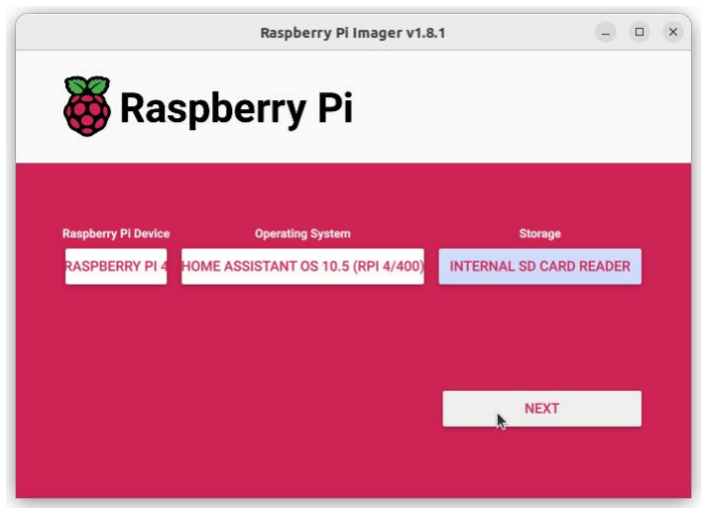
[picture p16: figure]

## 8. Eject the SD card. 9. Start Raspberry Pi

(1) Insert the SD card into the Raspberry Pi. (2) Plug in the Ethernet cable and make sure the Raspberry Pi is connected to the same network

as your computer.

(3) Connect the power supply and start the device. 10. start the Raspberry Pi, start after the completion of we can see

## the LAN ip address and port information, 8123 is the management

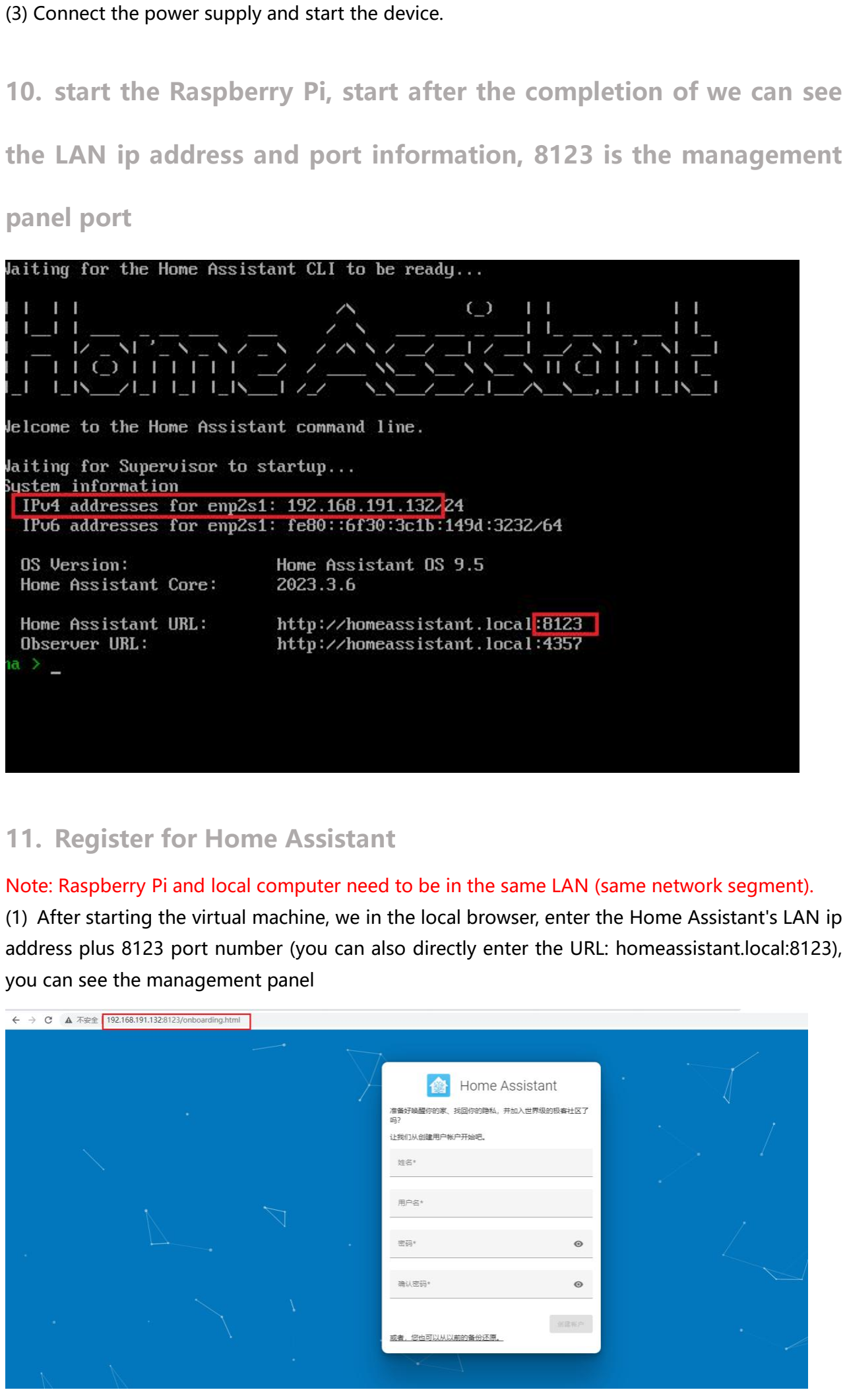
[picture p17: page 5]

## panel port

## 11. Register for Home Assistant

Note: Raspberry Pi and local computer need to be in the same LAN (same network segment). (1) After starting the virtual machine, we in the local browser, enter the Home Assistant's LAN ip

address plus 8123 port number (you can also directly enter the URL: homeassistant.local:8123), you can see the management panel

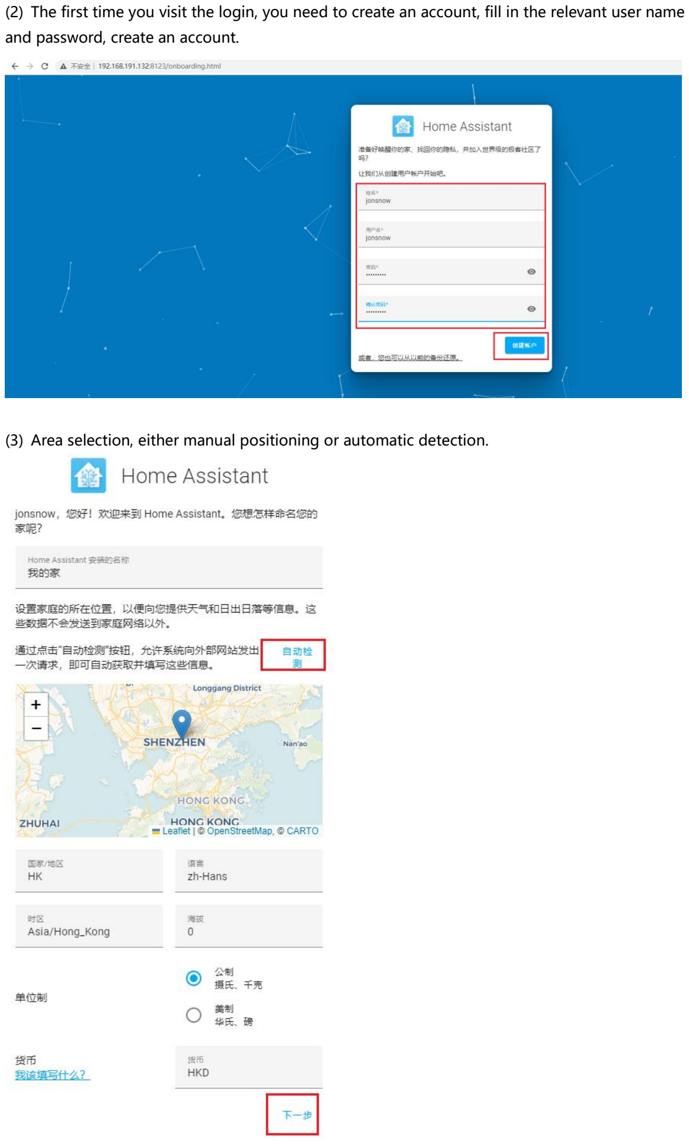
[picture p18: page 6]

(2) The first time you visit the login, you need to create an account, fill in the relevant user name and password, create an account.
(3) Area selection, either manual positioning or automatic detection.

(4) Next click Next by default

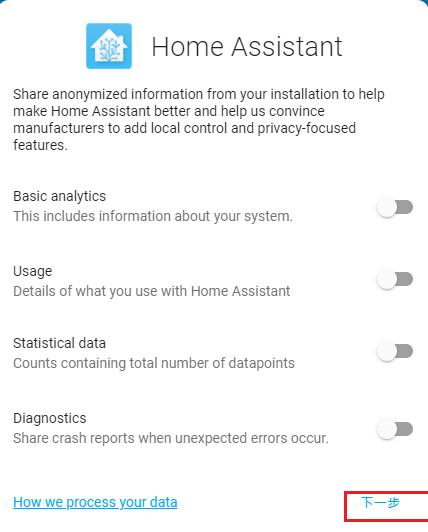
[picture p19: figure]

(5) Then click Finish, here prompted to add a smart device, you can click Finish, and then set up your own settings.

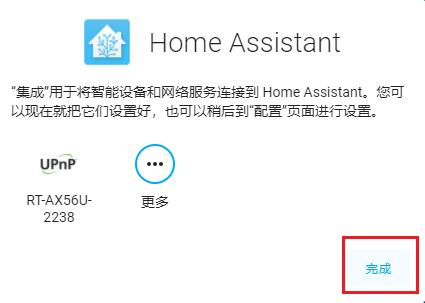
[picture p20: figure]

(6) Then you're in the control panel screen

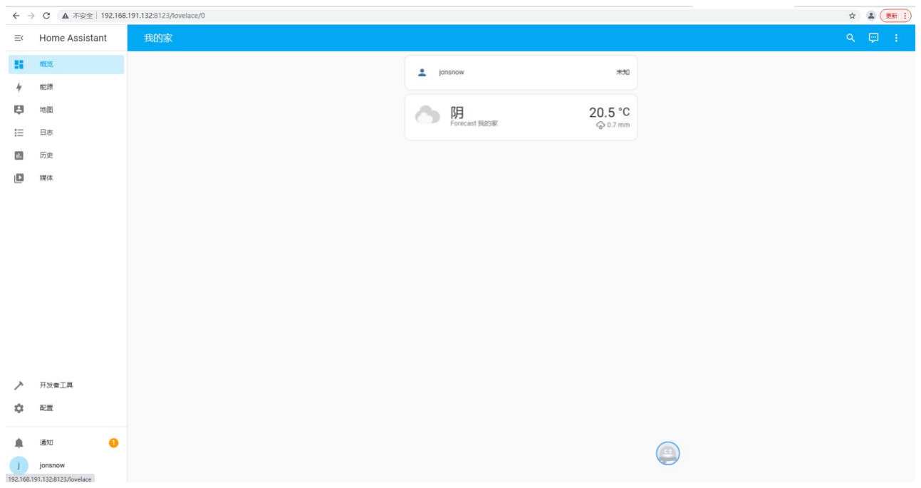
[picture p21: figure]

## 12. Configuring MQTT

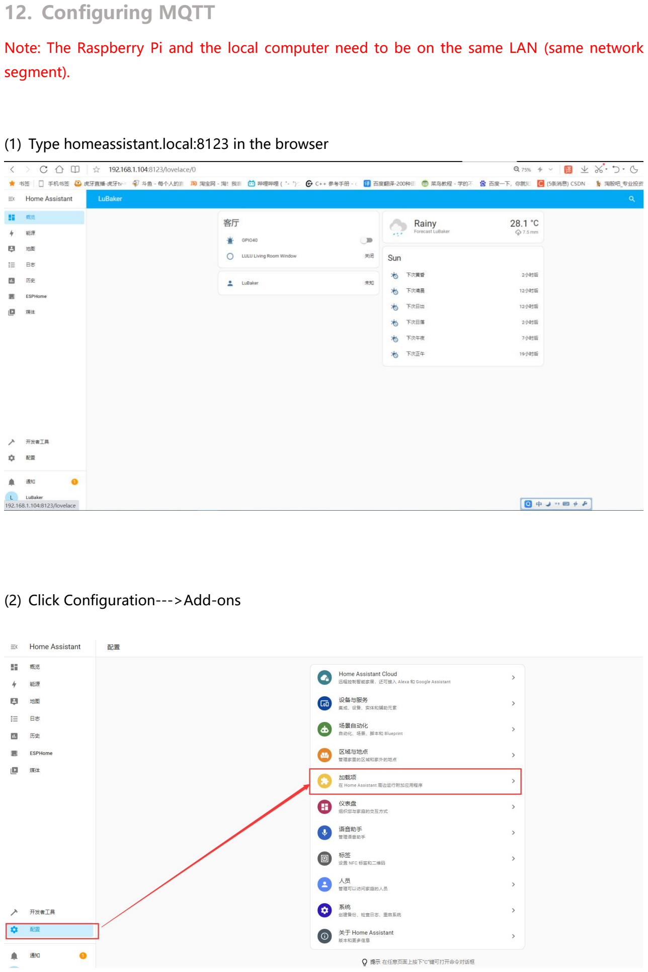
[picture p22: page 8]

Note: The Raspberry Pi and the local computer need to be on the same LAN (same network segment).

(1) Type homeassistant.local:8123 in the browser
(2) Click Configuration--->Add-ons

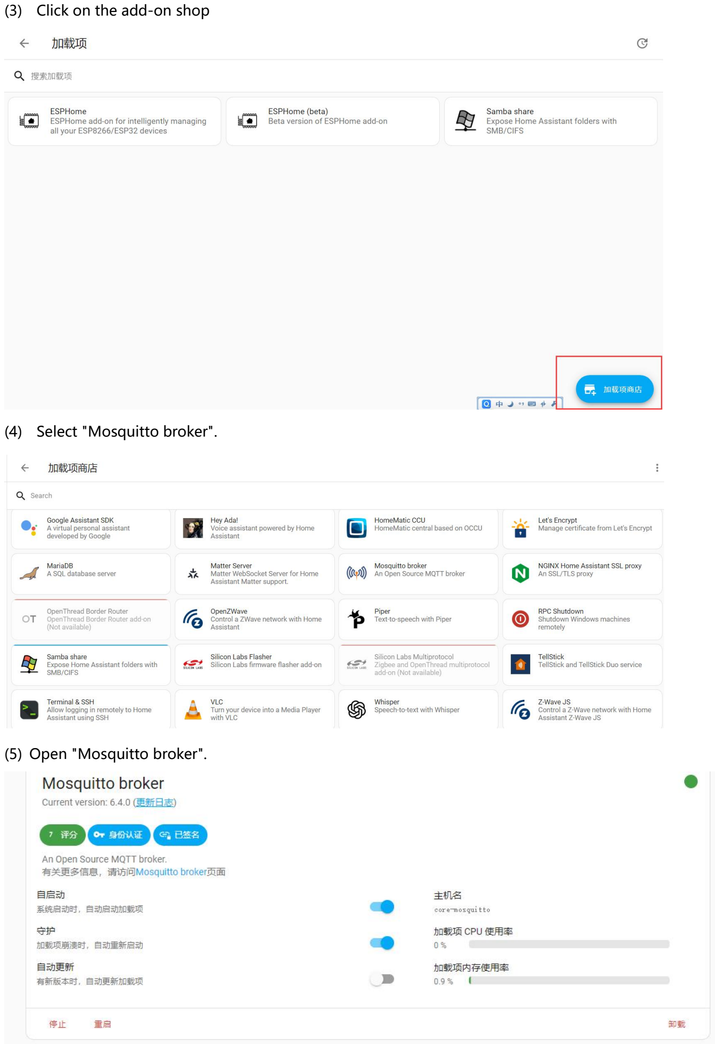
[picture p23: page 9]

(3) Click on the add-on shop
(4) Select "Mosquitto broker".
(5) Open "Mosquitto broker".

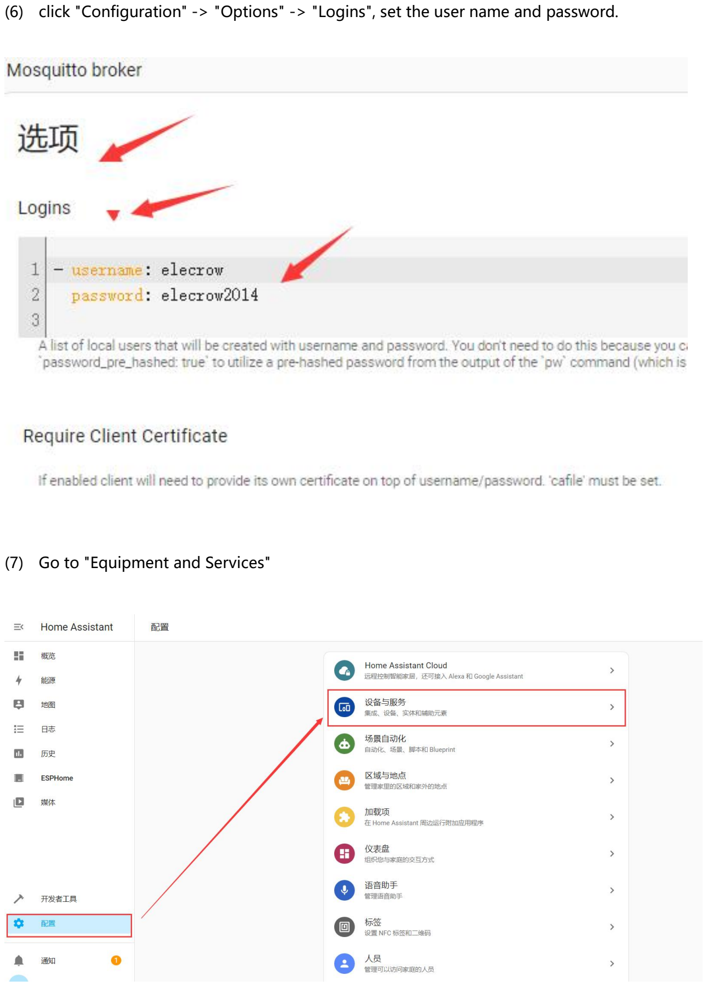
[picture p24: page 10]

(6) click "Configuration" -> "Options" -> "Logins", set the user name and password.
(7) Go to "Equipment and Services"

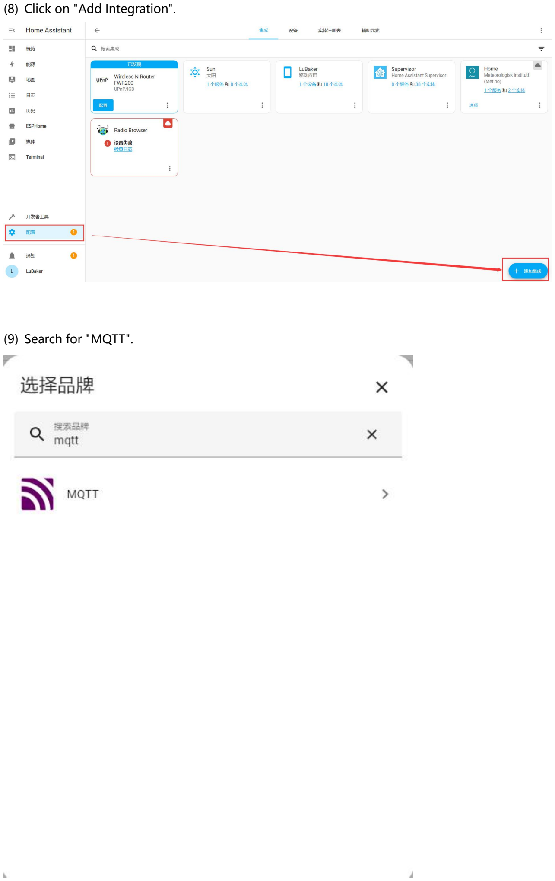
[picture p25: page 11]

(8) Click on "Add Integration".
(9) Search for "MQTT".

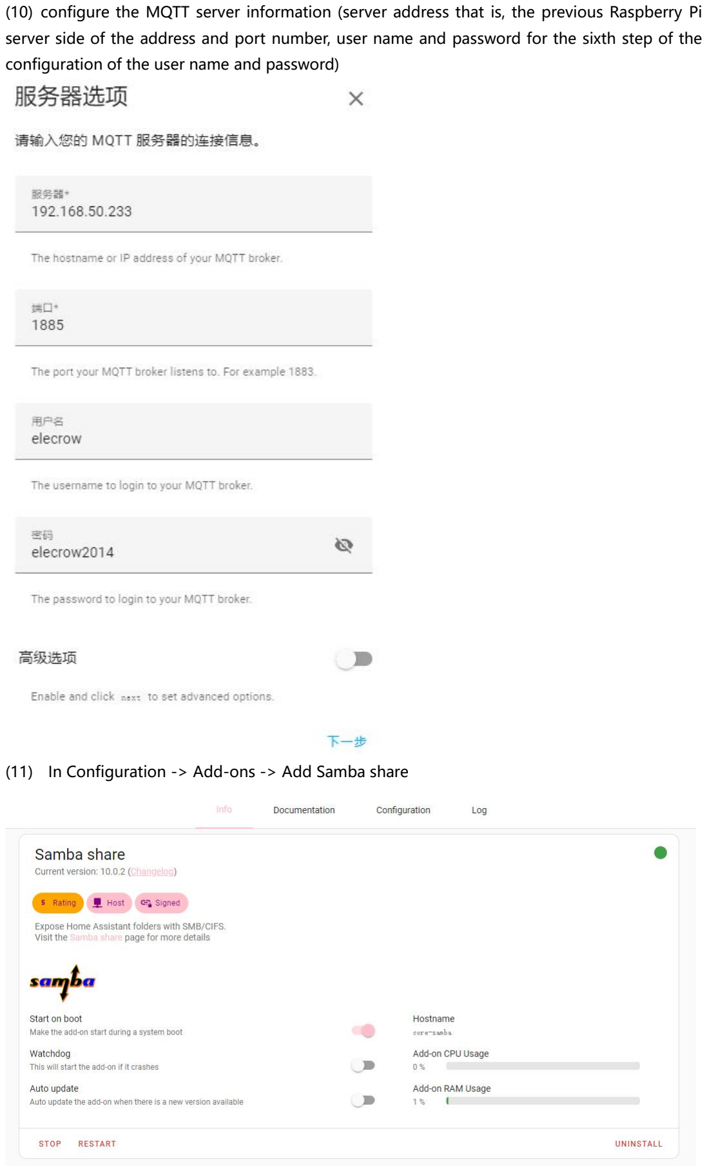
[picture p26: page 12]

(10) configure the MQTT server information (server address that is, the previous Raspberry Pi server side of the address and port number, user name and password for the sixth step of the configuration of the user name and password)
(11) In Configuration -> Add-ons -> Add Samba share

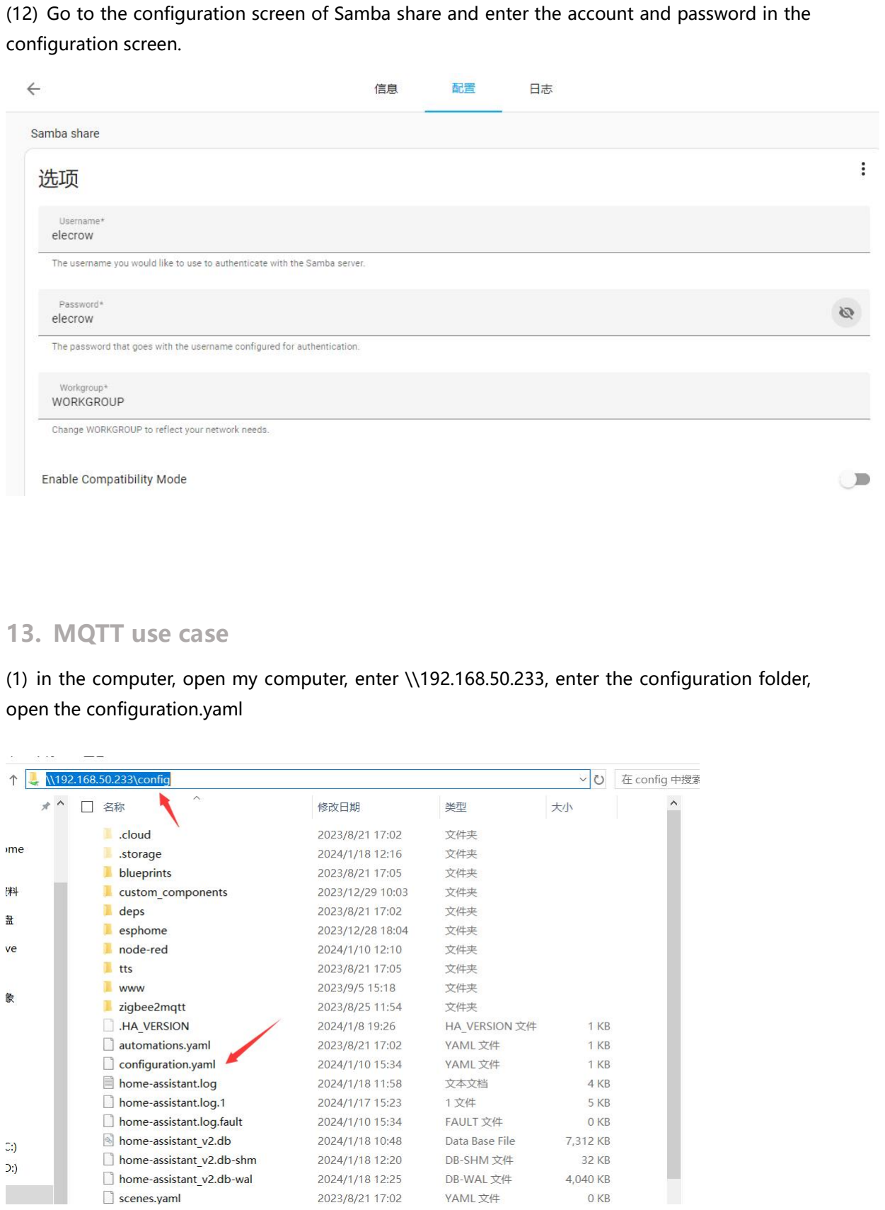
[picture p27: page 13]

(12) Go to the configuration screen of Samba share and enter the account and password in the configuration screen.

## 13. MQTT use case

(1) in the computer, open my computer, enter \\192.168.50.233, enter the configuration folder, open the configuration.yaml


(2) Add a light and temperature/humidity sensor module by entering the following code in configuration.yaml. You need to pay attention to the format indentation, you can refer to the following figure for format indentation.

mqtt:
light:
- name: "led"
state_topic: "esp32/led/state"

command_topic: "esp32/led/command" payload_on: "ON"
payload_off: "OFF"
sensor:
- name: "Temperature"
state_topic: "esp32/temperature" unit_of_measurement: "°C"
- name: "Humidity"
state_topic: "esp32/humidity" unit_of_measurement: "%" Above belongs to the configuration in yaml file to enable lights and sensors with brightness. For
more knowledge refer to the link: https://www.home-assistant.io/integrations/light.mqtt/. 14. After | saving | the | above | code, | go | to | the | main

## interface->Overview->Edit Dashboard->Add Card->Select the entity

## just written in configuration.yaml in the card->Click Finish to

complete the addition.


## 15. Burn the corresponding arduino code for the screen. (Refer to

## "5.0inch_Squareline_Demo Download Introduction" document)

## 16. Server-side effect display


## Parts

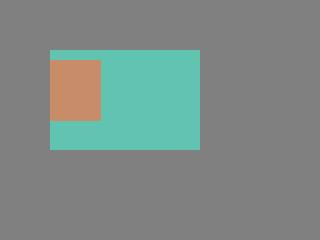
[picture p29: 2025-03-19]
example/V3.0/ESP_IDF/LVGL_Control_LED_50/components/lvgl-9/docs/misc/par_child3.png

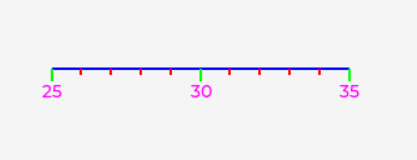
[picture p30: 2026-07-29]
example/V3.0/ESP_IDF/LVGL_Control_LED_50/components/lvgl-9/docs/misc/scale.png

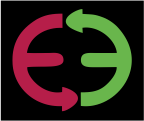
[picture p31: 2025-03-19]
example/V1.0_and_V2.0/ESP_IDF/CrowPanel_ESP32_5.0/components/lvgl-3/src/examples/assets/toppic.png

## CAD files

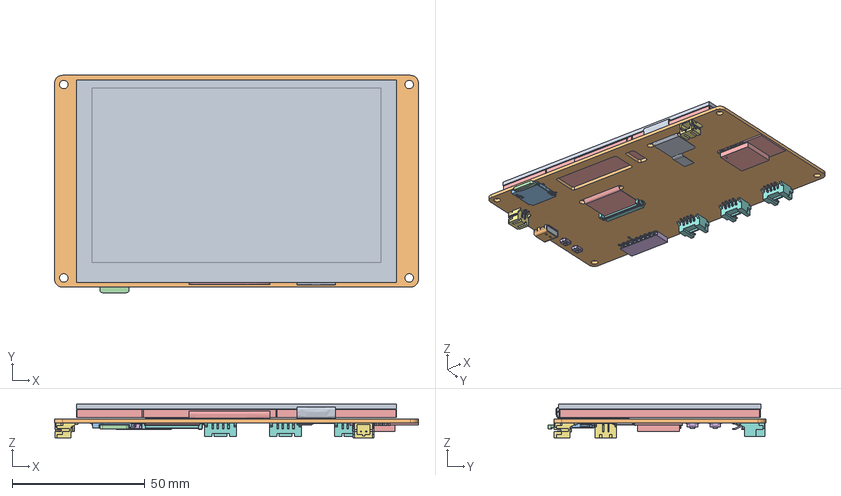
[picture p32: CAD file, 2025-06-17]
3D file/3d_file_crowpanel_5_0-esp32_hmi_asm.stp
137.2 x 82.0 x 12.6 mm
5IN-PCB-0221_A_4
BREP_1-383_1
BREP_2-384_1
BREP_8_1
BREP_9_1
BREP_10_1
BREP_11_1
BREP_12_1
BREP_13_1
BREP_14_1
BREP_15_1
BREP_16_1
BREP_17_1
BREP_18_1
BREP_19_1
BREP_20_1
BREP_21_1
BREP_22_1
BREP_23_1
BREP_24_1
BREP_25_1
BREP_26_1
BREP_27_7
BREP_31_1
BREP_33_1
BREP_32_1 x 2
HD_2
5IN-JZ_2
CROWPANEL_ESP32_DISPLAY-5_0-INC

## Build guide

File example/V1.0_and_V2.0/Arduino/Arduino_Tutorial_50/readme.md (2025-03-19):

# Libraries Overview

## Adafruit_BusIO
Adafruit BusIO is a library designed to simplify communication over various buses like I2C, SPI, and UART on microcontrollers.

## Adafruit_GFX_Library
The Adafruit GFX Library provides a set of functions for drawing graphics on displays connected to microcontrollers.

## Adafruit_SSD1306
Adafruit SSD1306 is a library specifically tailored for interfacing with SSD1306-based OLED displays.

## BLE
Bluetooth Low Energy (BLE) libraries enable wireless communication between devices using BLE technology, often utilized in Internet of Things (IoT) applications.

## Crowbits_DHT20
Crowbits DHT20 library facilitates reading temperature and humidity data from DHT20 sensors.

## EEPROM
EEPROM stands for Electrically Erasable Programmable Read-Only Memory; this library manages persistent storage on microcontrollers.

## ESP32-audioI2S-master
ESP32 Audio I2S Master library enables audio processing on ESP32 microcontrollers through the Inter-IC Sound (I2S) interface.

## FFat
FFat refers to FatFs File System, allowing file management on storage devices such as SD cards.

## FS
FS typically denotes File System libraries, providing functionalities for organizing and accessing files stored on non-volatile memories.

## gt911-arduino-main
gt911 Arduino Main library supports touch screen operations by interpreting touch inputs from GT911 capacitive touch controllers.

## LovyanGFX
LovyanGFX is an advanced graphics library offering high-performance rendering capabilities suitable for complex graphical user interfaces.

## lvgl
LVGL (Light and Versatile Graphics Library) is a free and open-source graphics library enabling developers to create visually appealing GUIs efficiently.

## SD
SD library handles operations related to Secure Digital (SD) card storage, including reading/writing files and directory navigation.

## SD_MMC
SD MMC library extends functionalities provided by standard SD libraries to include MultiMediaCard (MMC) support as well.

## lv_conf.h
lv_conf.h contains configuration settings for LVGL library specifying memory allocation sizes, feature toggles, default styles etc., influencing application behavior and appearance.

## touch.h
touch.h defines necessary functions and structures required for detecting and interpreting touch events originating from touchscreens or similar input devices.

## UI-5.0-BLUE.rar
UI-5.0-BLUE.rar seems to be a compressed archive holding user interface elements possibly meant for deployment within projects requiring visual components labeled under 'UI-5.0-BLUE' theme/versioning scheme.

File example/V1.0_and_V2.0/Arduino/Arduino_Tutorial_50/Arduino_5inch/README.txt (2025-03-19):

1. For whose silkscreen SKU on the back is WZ8048C050, please use the sample program named "HMI-5" in folder Hardware-Version-1.0.

2. For whose silkscreen SKU on the back is DIS07050H, please use the sample program named "LvglWidgets-5.0-NOSPEAK" in folder Hardware-Version-2.0, because it adds an IIC interface and requires Adafruit_GFX_Library and Adafruit_SSD1306.

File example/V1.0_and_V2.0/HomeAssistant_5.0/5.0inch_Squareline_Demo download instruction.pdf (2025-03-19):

# 5.0inch_Squareline_Demo Download Introduction

## 1. Operation before downloading cases

(1) Place all the lib library files provided in the folder into the libraries file of the

arduino.

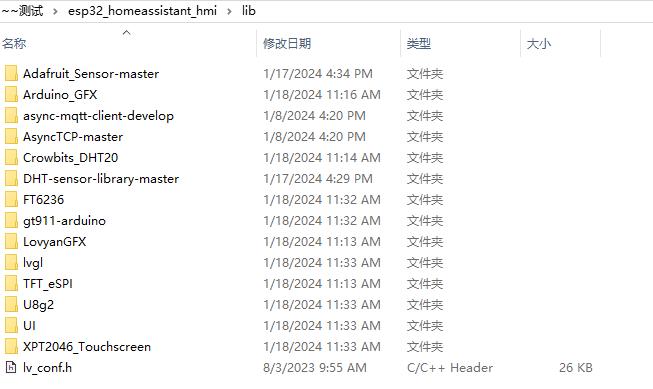
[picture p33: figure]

## Sensor wiring:

(1) Temperature and humidity sensor (Crowtail-DHT20-V1.0) with IIC interface

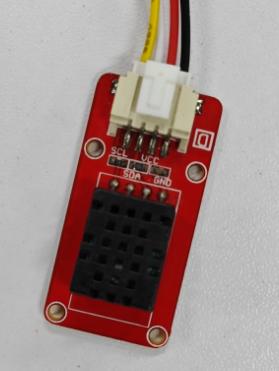
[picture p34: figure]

(2) LED to IO38 port

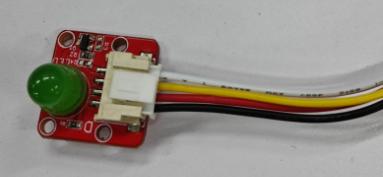
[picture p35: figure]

2. Use | arduino | software | to | open

## 5.0inch_Squareline_Demo.ino, arduino related operations

## can refer to this screen wiki

（https://www.elecrow.com/wiki/index.php?title=ESP32_Display_5.0%27%27_Intelli

gent_Touch_Screen_Wi-Fi%26BLE_800*480_HMI_Display）

## Download Settings:

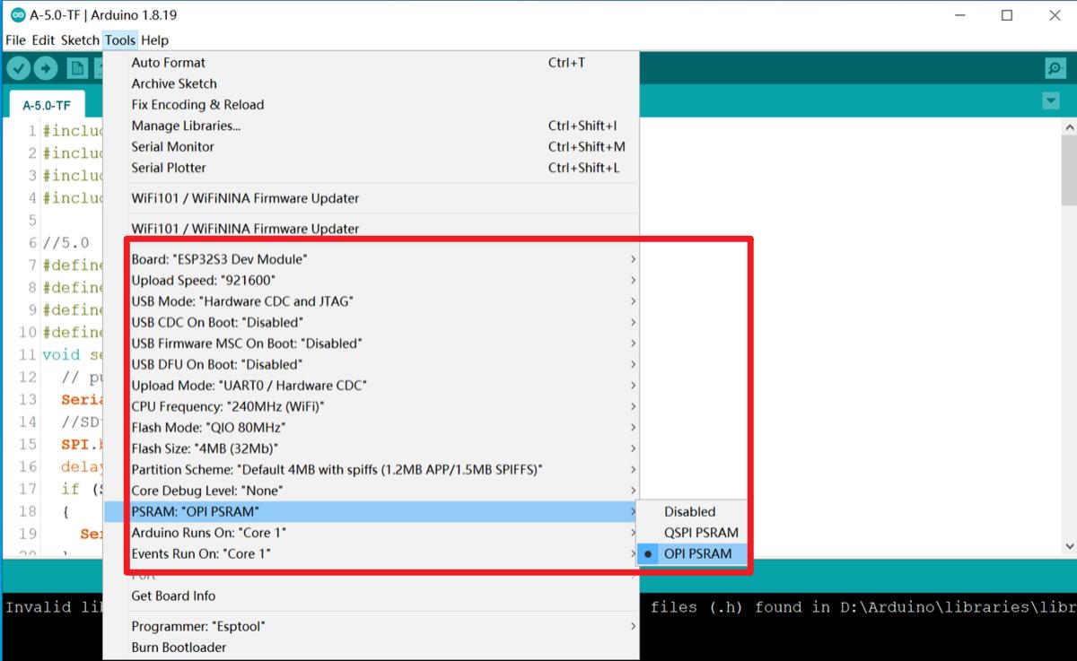
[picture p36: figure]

3. Download the programme. 4. Operational effects.

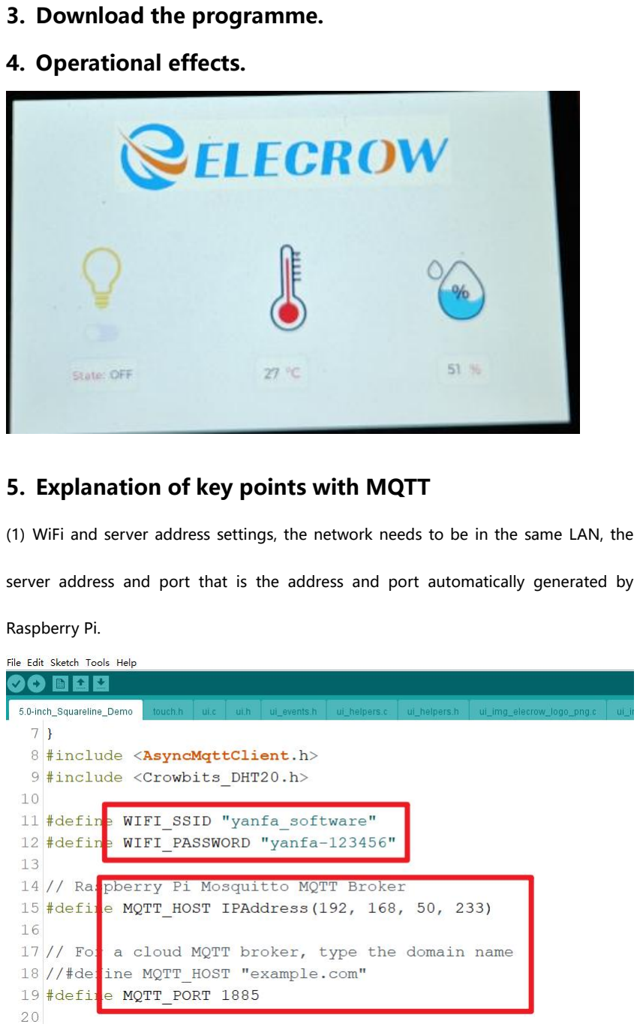
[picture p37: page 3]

## 5. Explanation of key points with MQTT

(1) WiFi and server address settings, the network needs to be in the same LAN, the

server address and port that is the address and port automatically generated by

Raspberry Pi.

(2) MQTT theme settings, the specific parameters are set according to the contents of

the configuration.yaml file on the MQTT server.

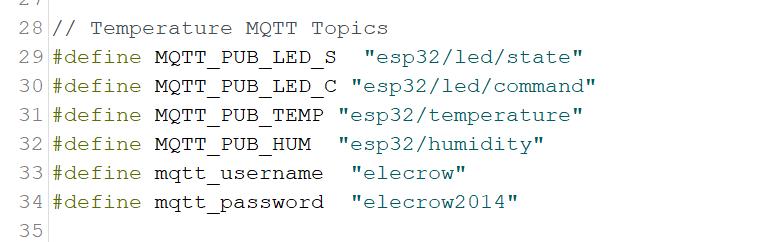
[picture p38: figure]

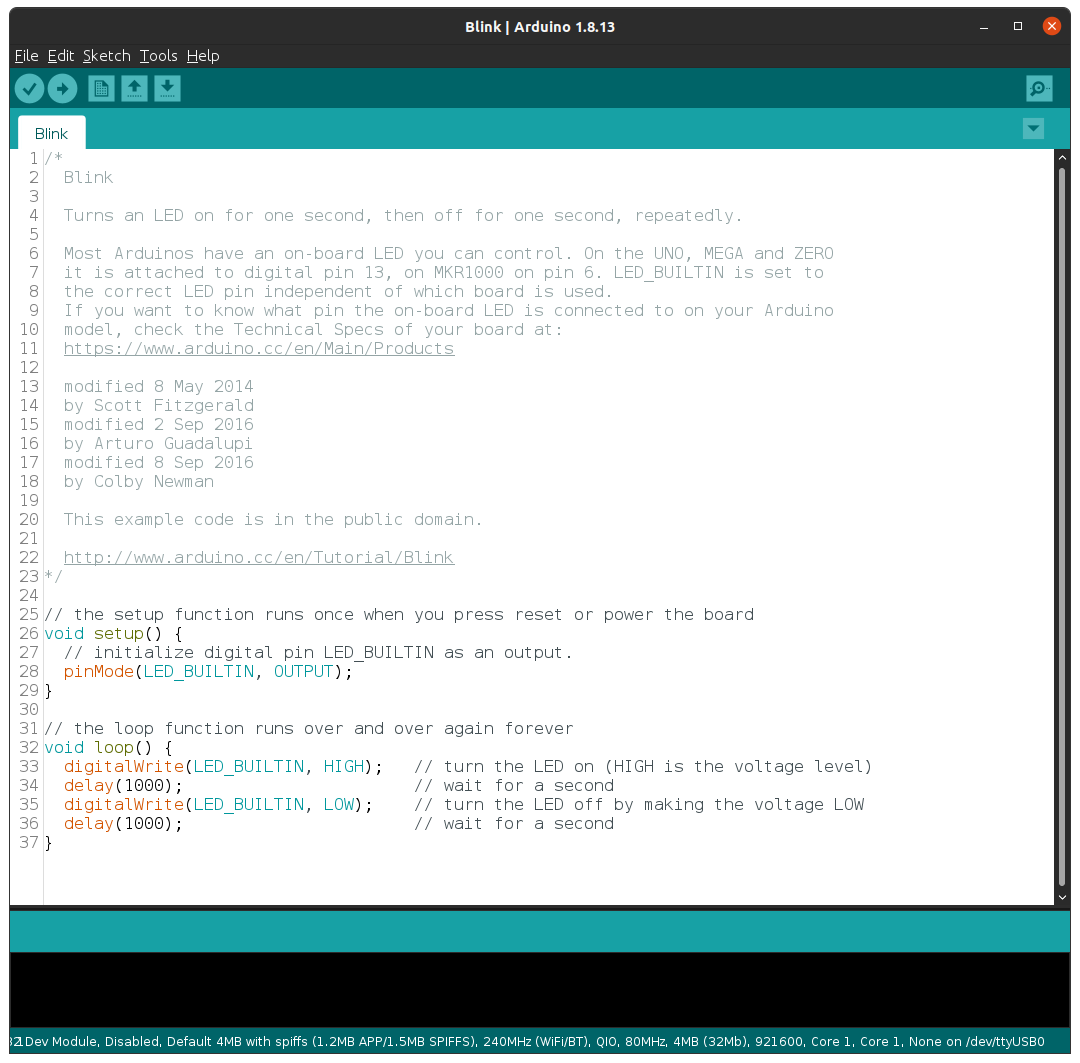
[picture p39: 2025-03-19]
example/V1.0_and_V2.0/ESP_IDF/CrowPanel_ESP32_5.0/components/arduino-esp32-master/docs/source/_static/tutorials/basic/tutorial_basic_ide.png

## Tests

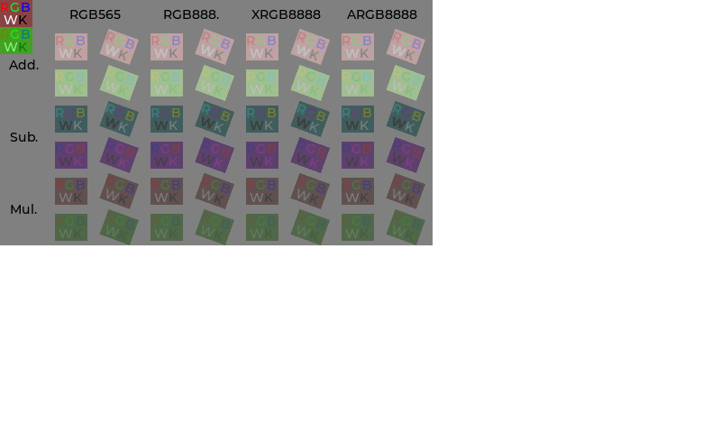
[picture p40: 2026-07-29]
example/V3.0/ESP_IDF/LVGL_Control_LED_50/components/lvgl-9/tests/ref_imgs/draw/render/xrgb8888/demo_render_blend_mode_opa_128.png

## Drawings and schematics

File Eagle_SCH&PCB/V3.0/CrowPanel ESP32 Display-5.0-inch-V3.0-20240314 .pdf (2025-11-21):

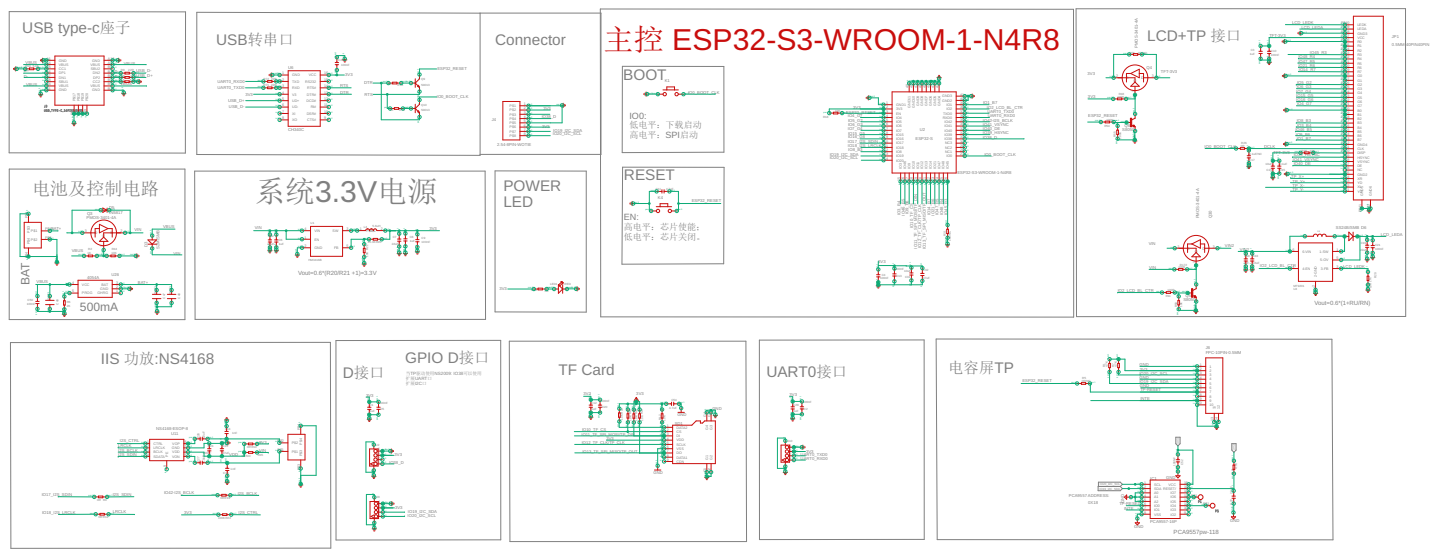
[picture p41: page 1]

pas 1 pas 1 pas 1 pas 1 sup 0 sup 0

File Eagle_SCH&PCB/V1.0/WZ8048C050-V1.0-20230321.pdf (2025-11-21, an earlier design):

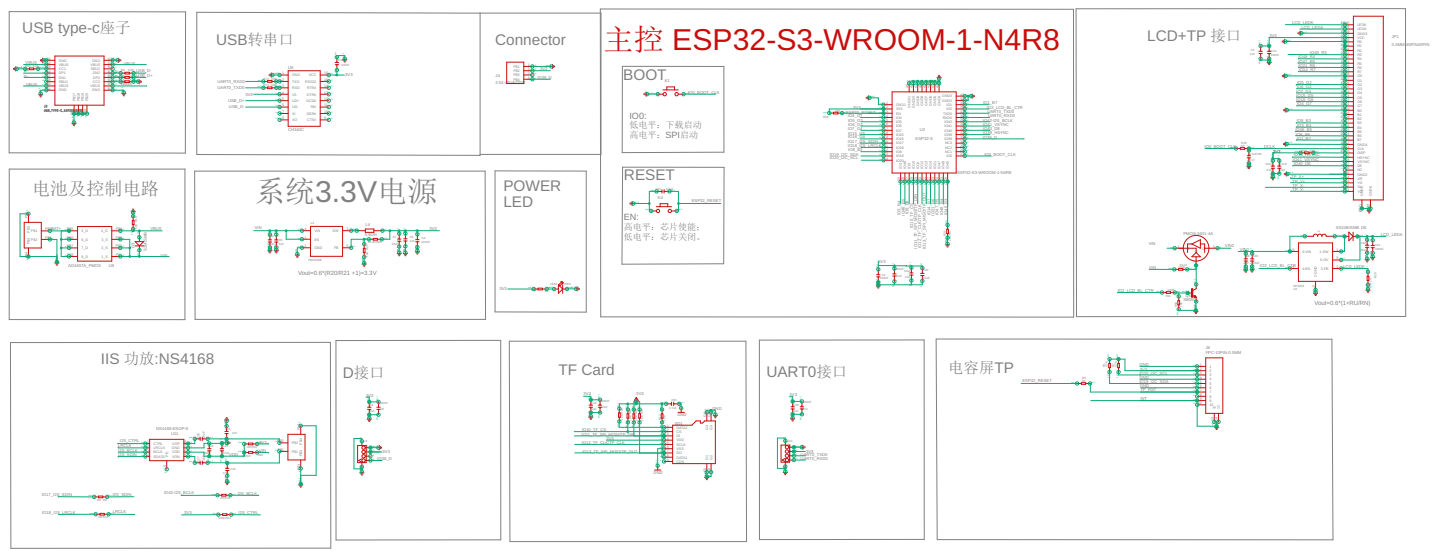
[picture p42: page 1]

pas 1 pas 1 pas 1 pas 1 sup 0 sup 0

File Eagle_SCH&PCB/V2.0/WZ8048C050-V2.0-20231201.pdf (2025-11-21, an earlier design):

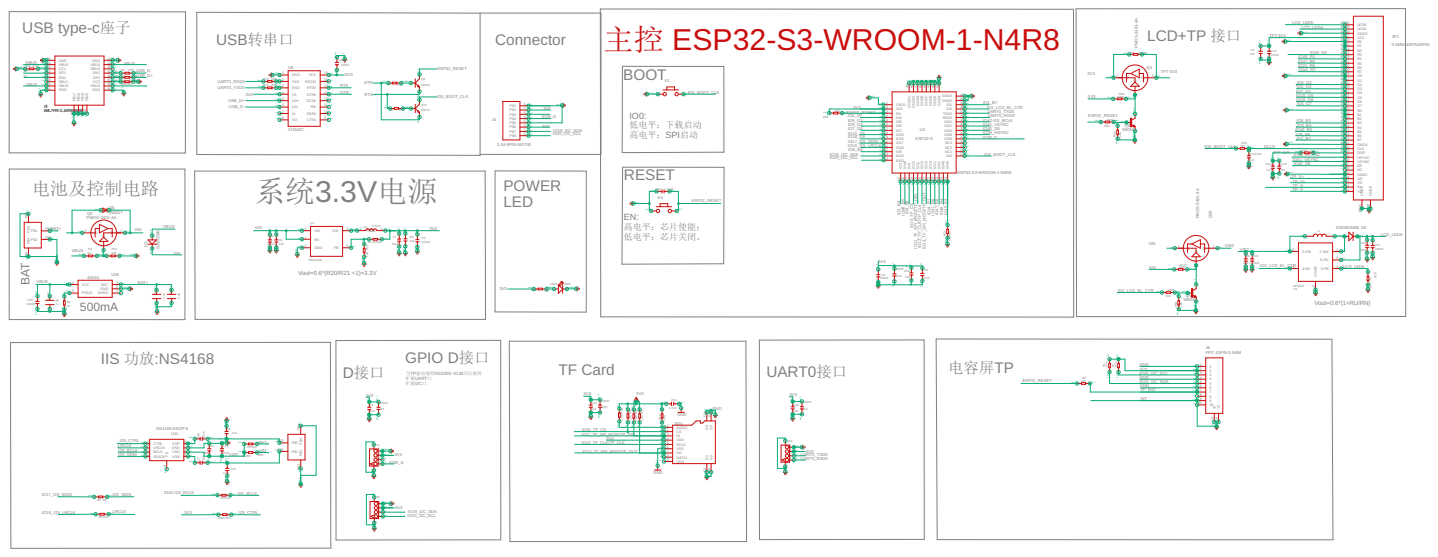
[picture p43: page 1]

pas 1 pas 1 pas 1 pas 1 sup 0 sup 0

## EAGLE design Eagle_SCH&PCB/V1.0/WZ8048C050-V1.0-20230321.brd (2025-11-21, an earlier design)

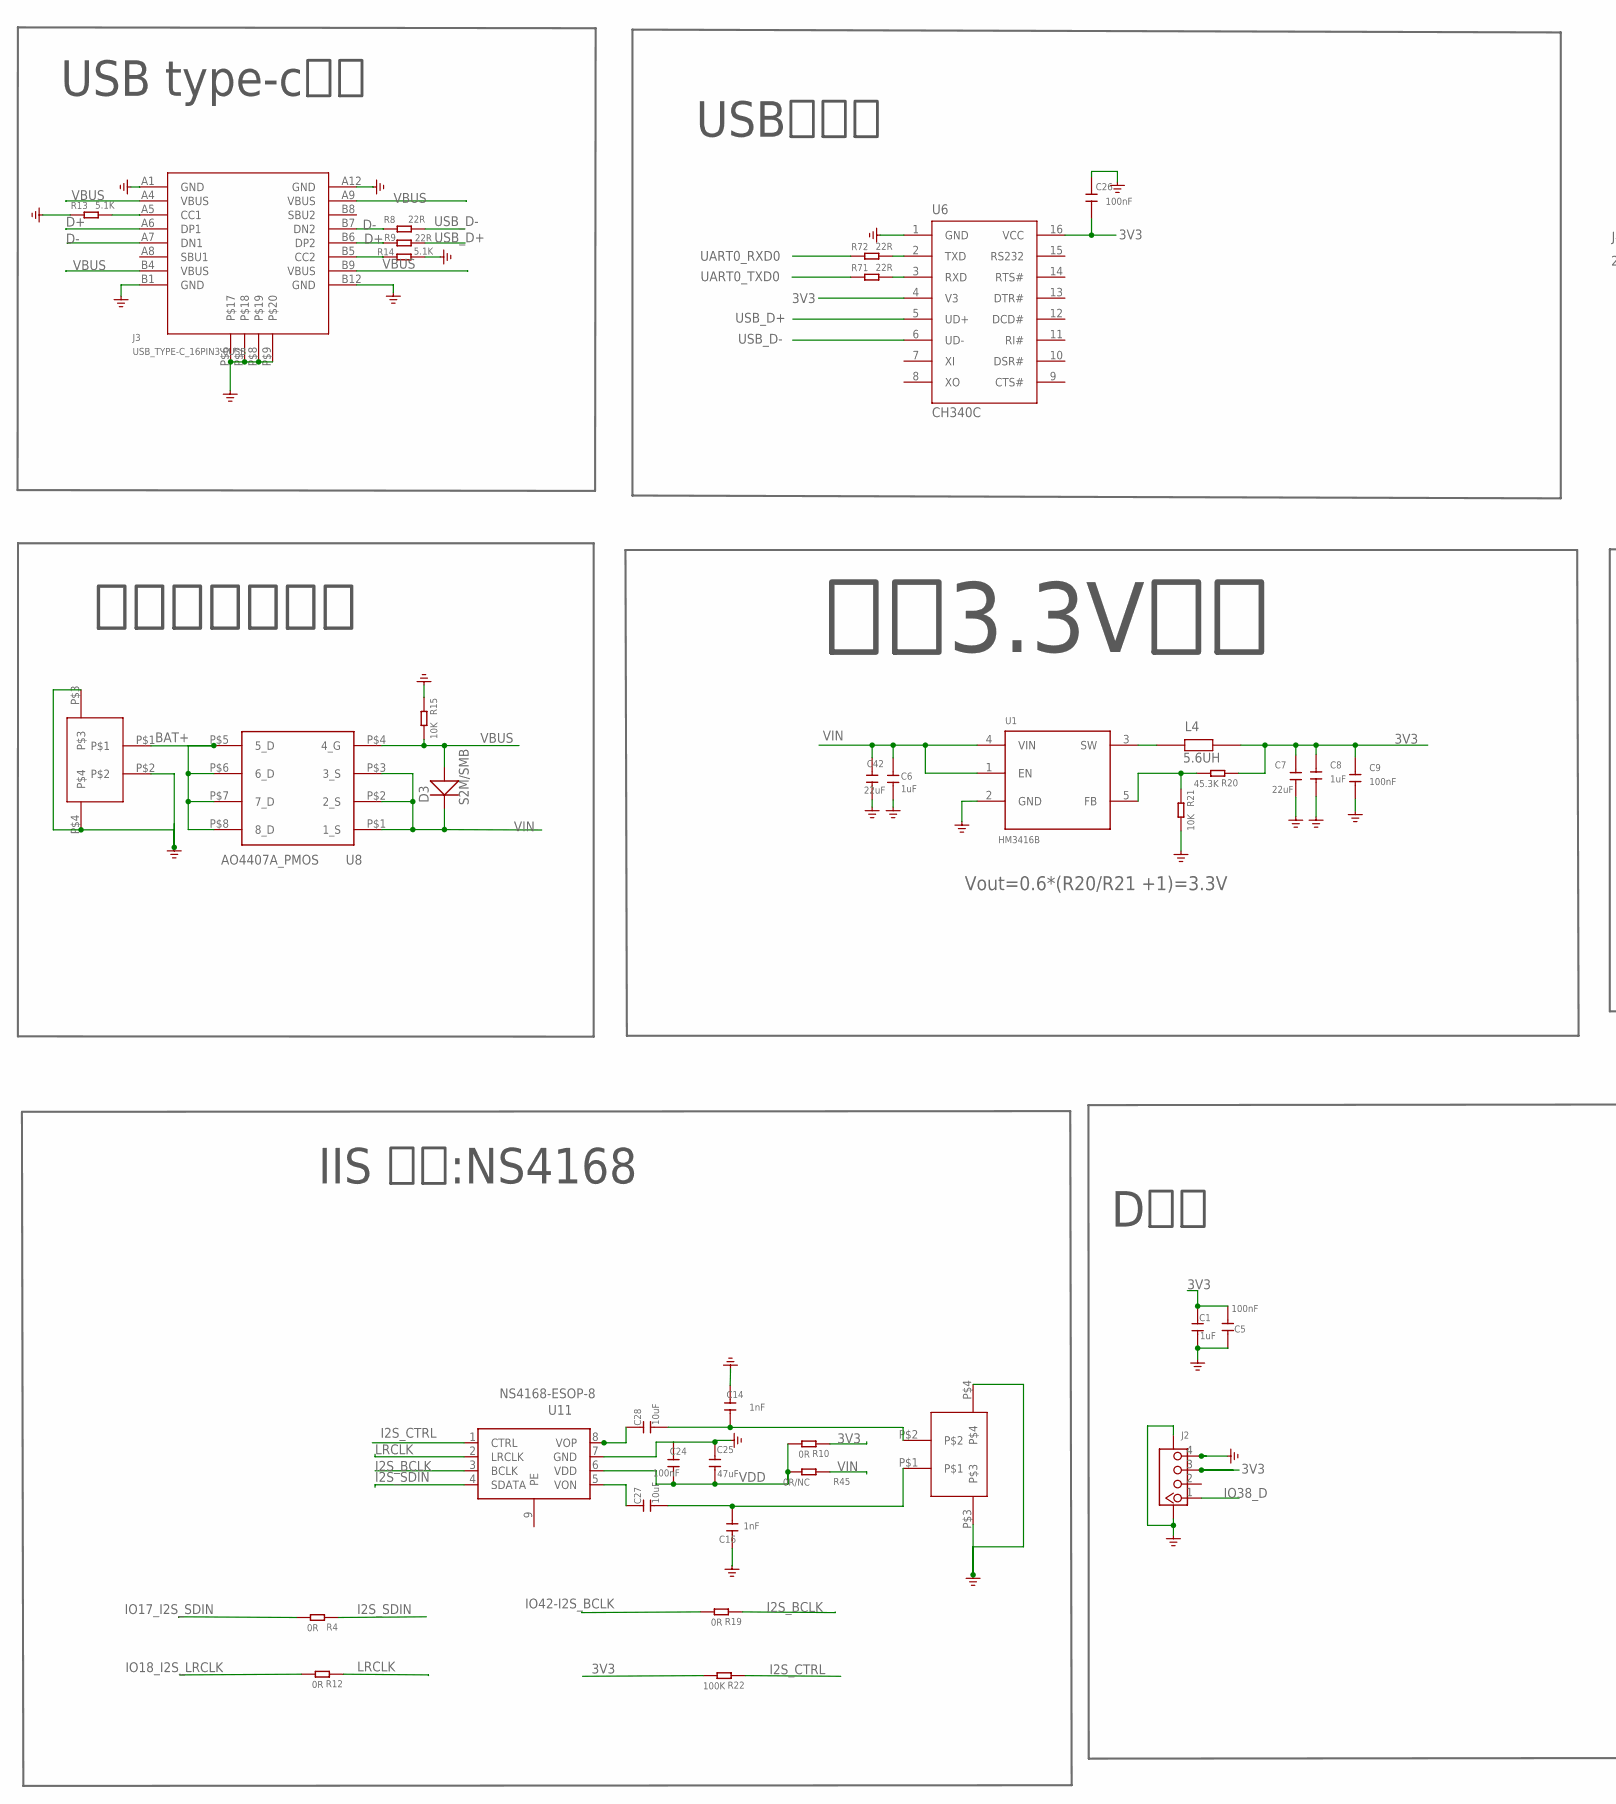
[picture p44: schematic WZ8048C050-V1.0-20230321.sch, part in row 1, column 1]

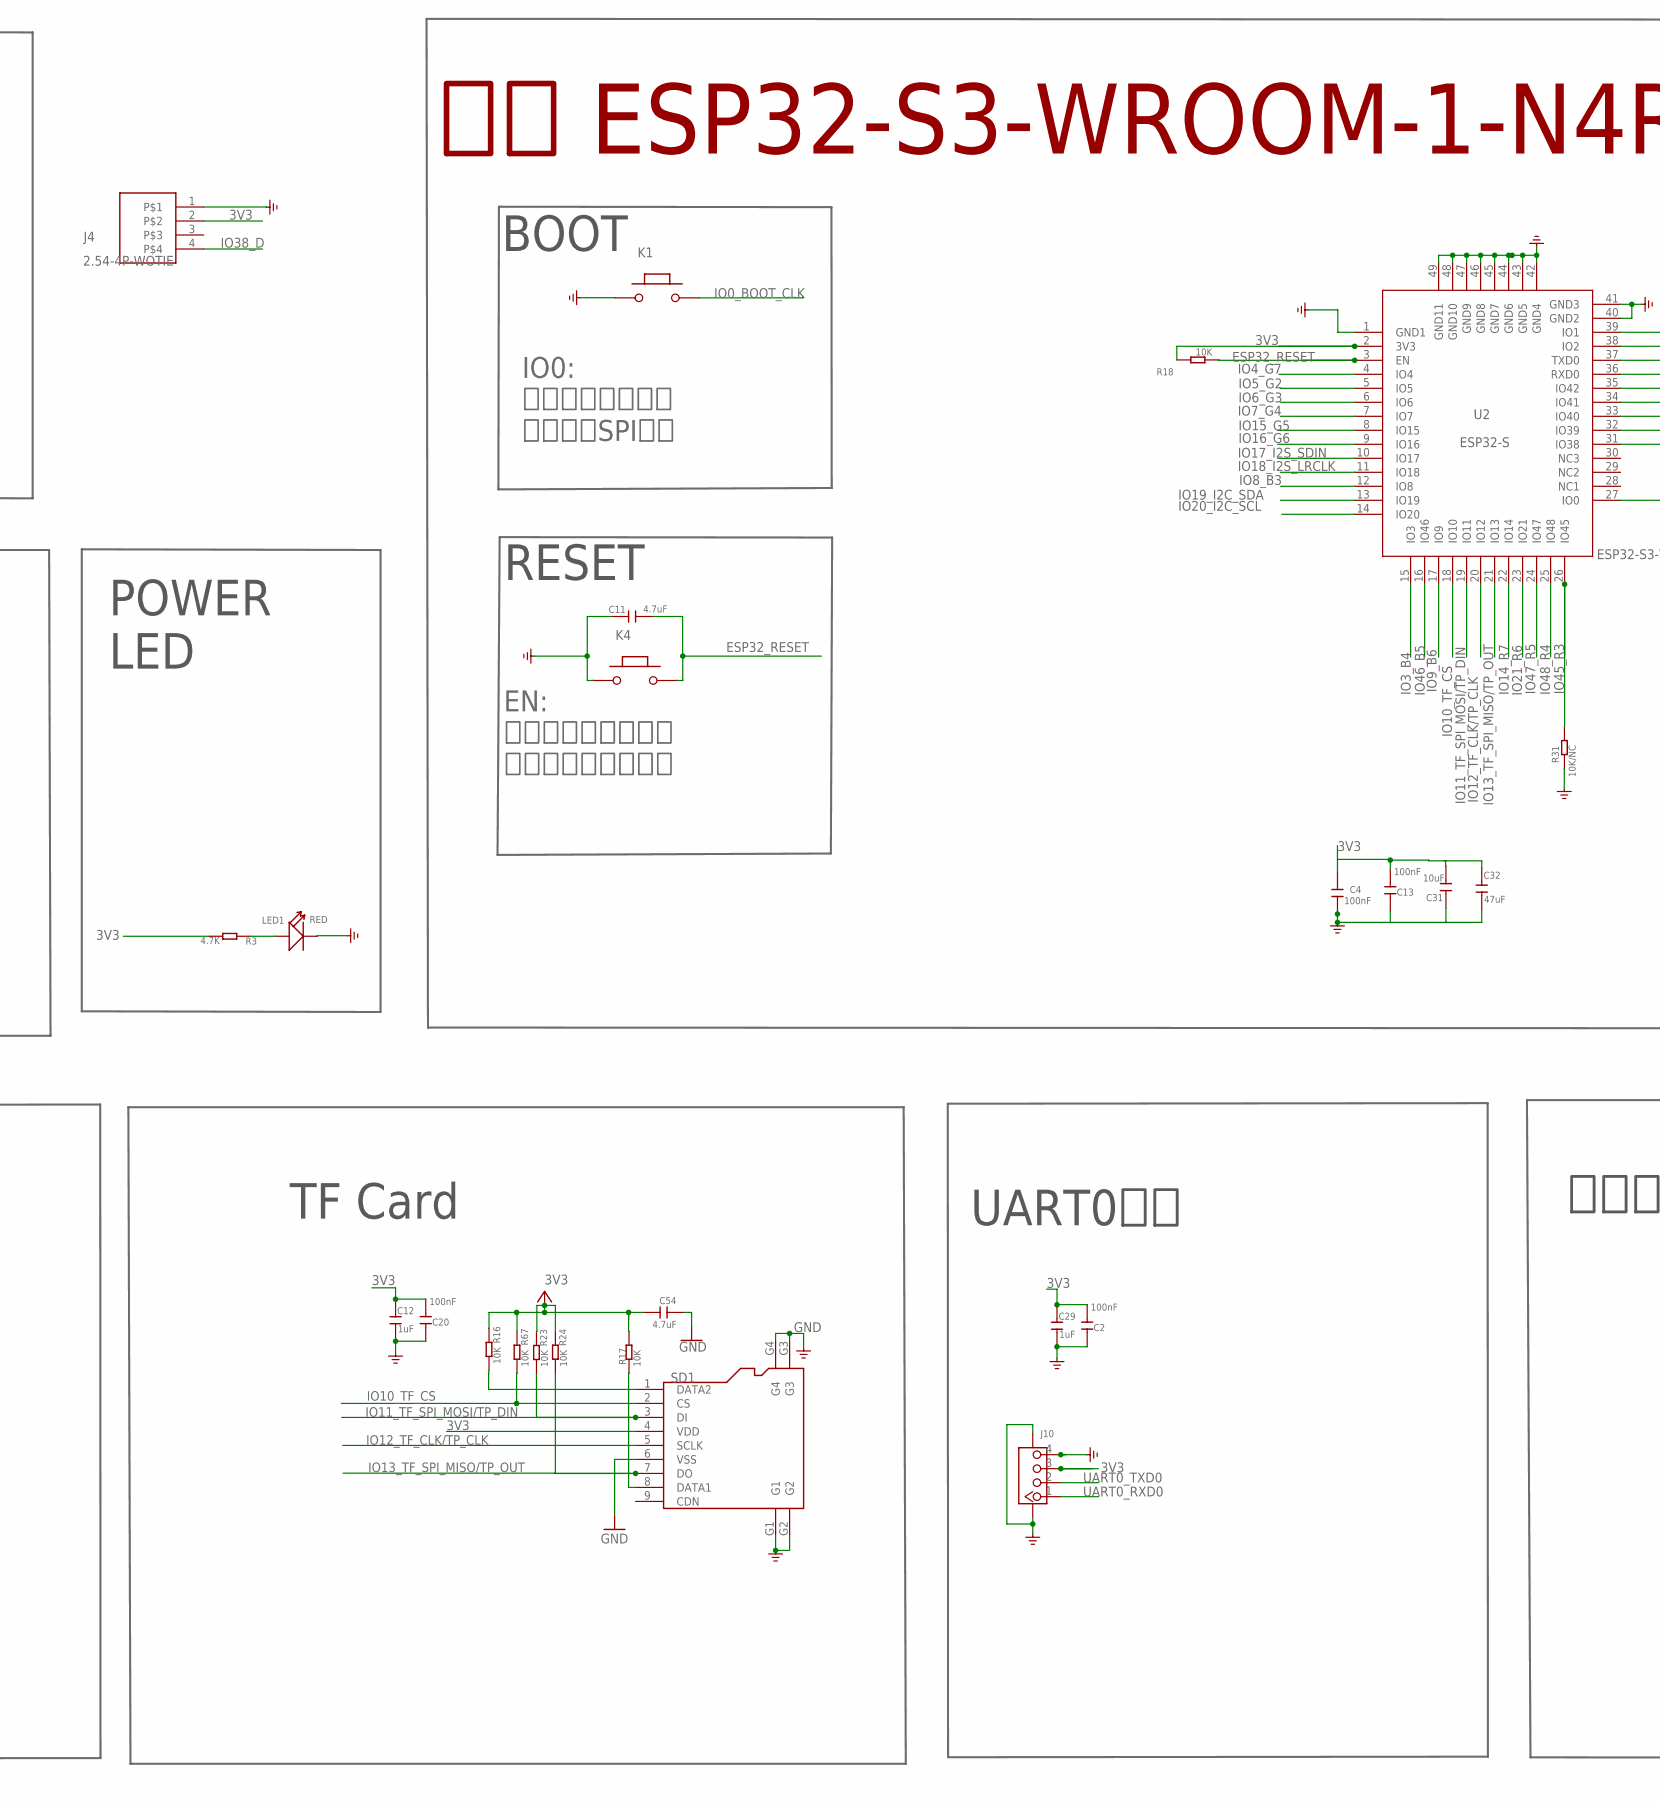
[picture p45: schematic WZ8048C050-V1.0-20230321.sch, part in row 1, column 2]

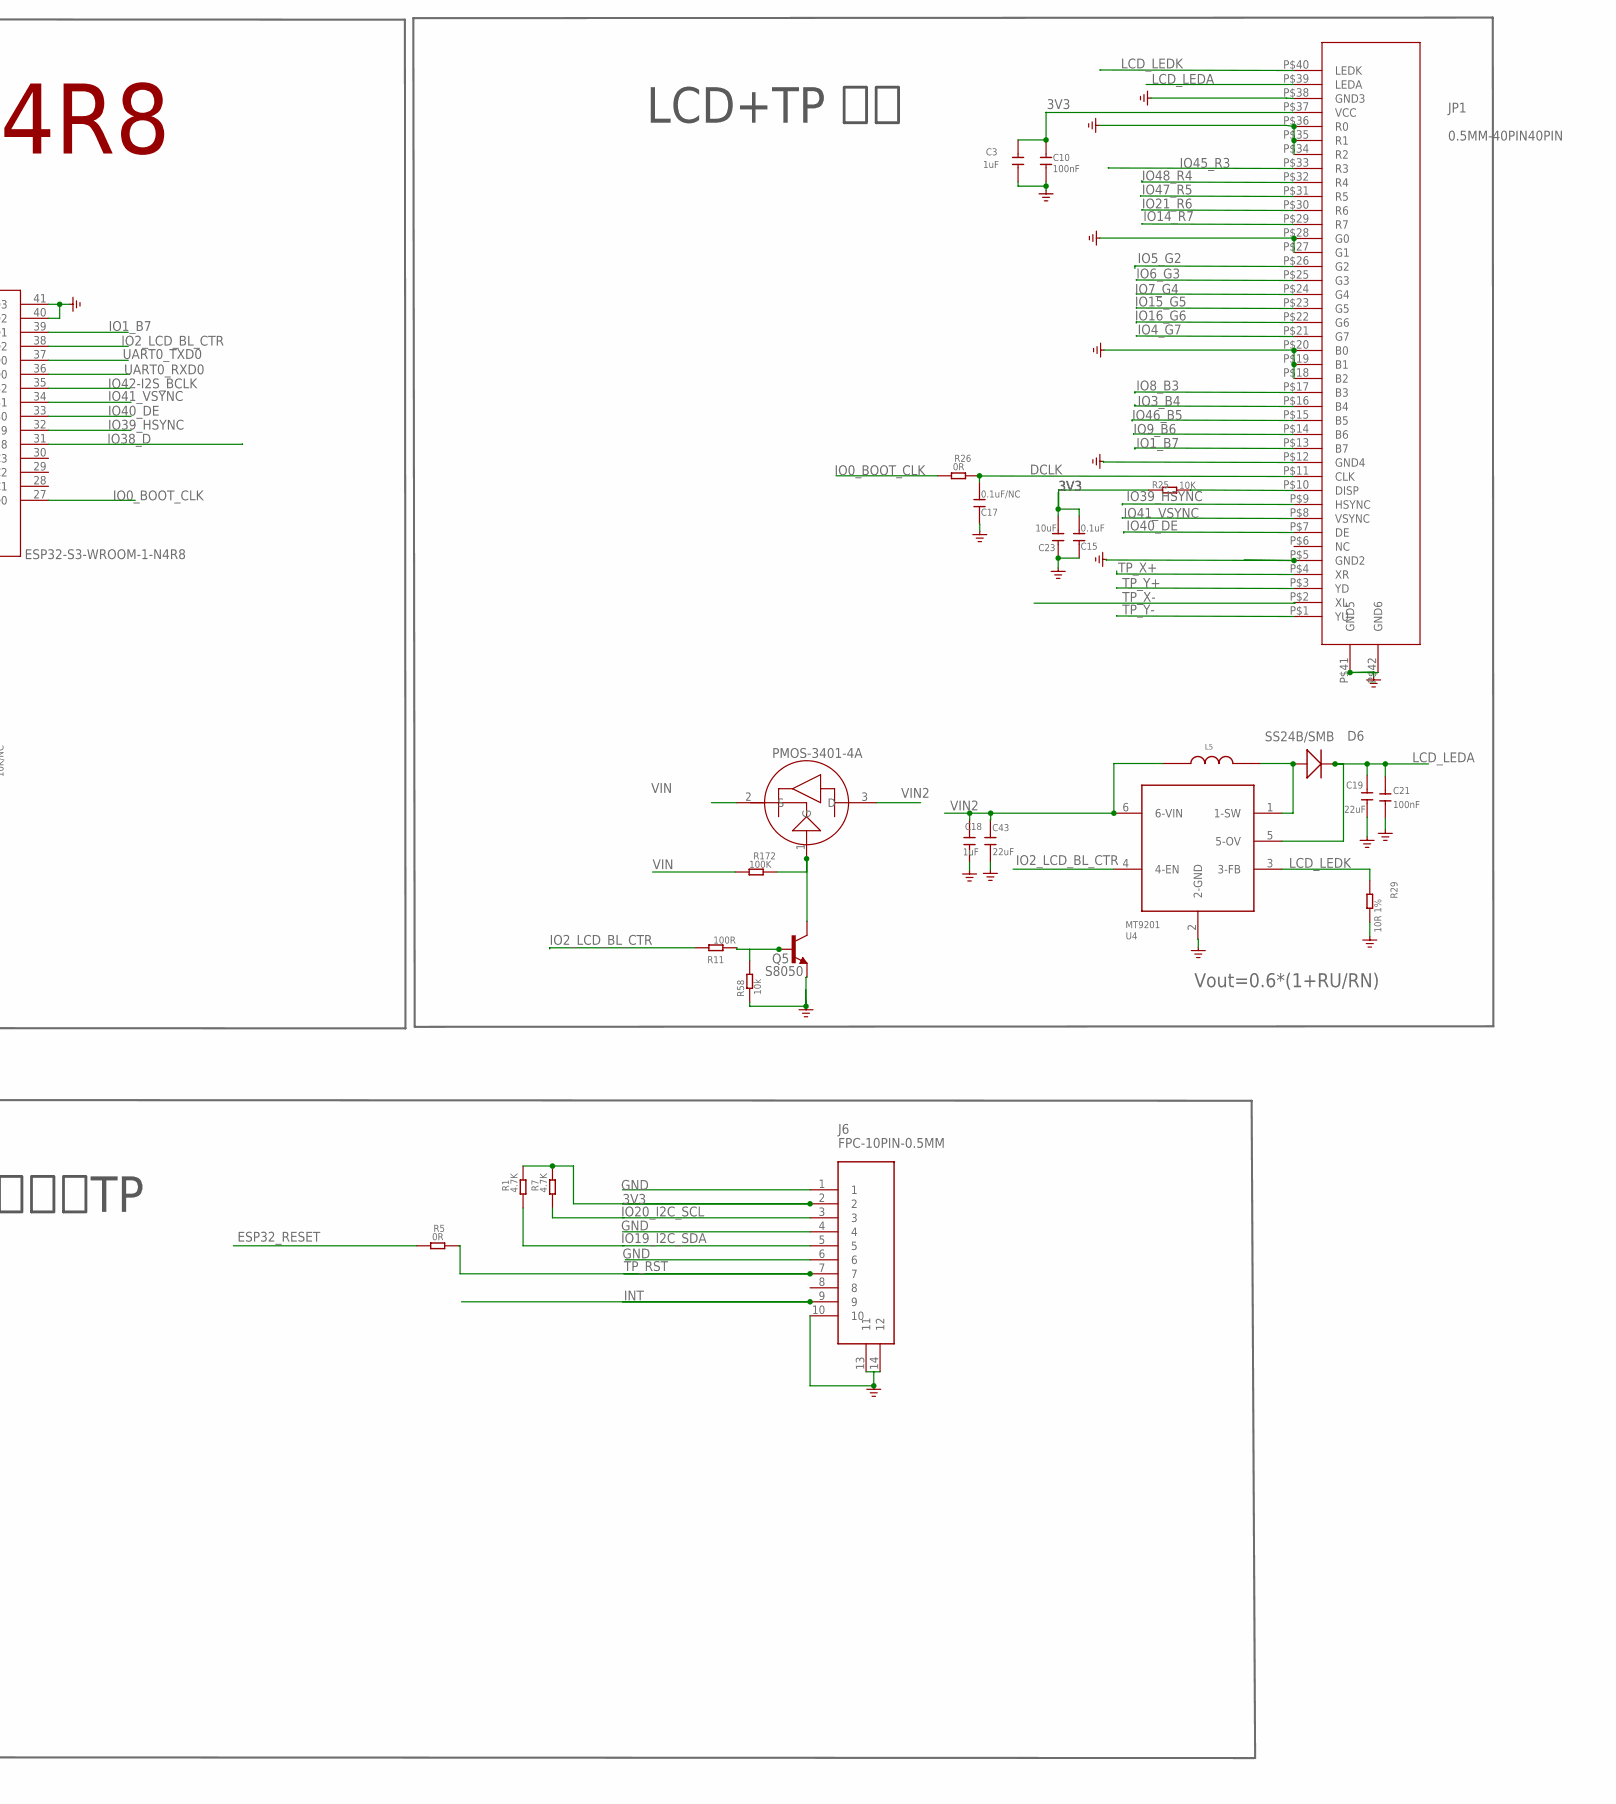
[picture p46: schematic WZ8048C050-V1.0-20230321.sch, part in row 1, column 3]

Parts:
C1, C12, C29: 1uF; DISCRETE_C0603
C2, C4, C5, C10, C13, C20, C24: 100nF; C0603
C3: 1uF; C0603
C6, C8, C18: 1uF; 0603
C7, C19, C42, C43: 22uF; 0805
C9, C21, C26: 100nF; 0603
C11: 4.7uF; 0603
C14, C16: 1nF; C0603
C15: 0.1uF; DISCRETE_C0603
C17: 0.1uF/NC; DISCRETE_C0603
C23, C27, C28, C31: 10uF; DISCRETE_C0603
C25, C32: 47uF; 0805
C54: 4.7uF; DISCRETE_C0603
D3: S2M/SMB; 214AB
D6: SS24B/SMB; 214AB
J1, J5: PH2.0WT-2PIN
J2, J10: CONNECTOR_TWIG-4P-2.0-SMD-FEMALE-REINFORCE90D; CONNECTOR_4P-SMD-2.0-90D
J3: USB_TYPE-C_16PIN3.0USB; KEVIN_3.0TYPEC-SMD
J4: 2.54-4P-WOTIE
J6: FPC-10PIN-0.5MM
JP1: 0.5MM-40PIN40PIN; 0.5MM*40P
K1, K4: BUTTON; 157SW
L4: 5.6UH; CD54
L5: CD32_6.8uH; CD32
LED1: RED; DISCRETE_LED-0603
Q5: S8050; SPARKFUN_SOT23
Q30: PMOS-3401-4A; SOT-23
R1, R7: 4.7K; R0603
R3: 4.7K; DISCRETE_R0603
R4, R10, R12, R19: 0R; DISCRETE_R0603
R5, R26: 0R; R0603
R8, R9, R71, R72: 22R; DISCRETE_R0603
R11: 100R; R0603
R13, R14: 5.1K; DISCRETE_R0603
R15, R16, R17, R18, R21, R23, R24, R25, R67: 10K; DISCRETE_R0603
R20: 45.3K; DISCRETE_R0603
R22: 100K; DISCRETE_R0603
R29: 10R 1%; DISCRETE_R0603
R31: 10K/NC; R0603
R45: 0R/NC; DISCRETE_R0603
R58: 10k; R0603
R172: 100K; R0603
SD1: HOLDER-MICROSD-9P; 9P-SMD-W/-RING
U1: HM3416B; A_XBJ_SOT23-5
U2: ESP32-S; ESP32-S3
U4: MT9201; SOT23-6
U6: CH340C; SOP-16
U8: AO4407A_PMOS; SOP8
U11: NS4168-ESOP-8

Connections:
3V3: C1.2, C2.1, C3.1, C4.2, C5.1, C7.2, C8.2, C9.2, C10.2, C12.2, C13.1, C15.2, C20.1, C23.2, C26.1, C29.2, C31.2, C32.2, C54.2, J2.3, J4.2, J6.2, J10.3, JP1.P$37 (VCC), L4.2, R1.2, R3.2, R7.2, R10.1, R16.1, R17.1, R18.1, R20.1, R22.2, R23.1, R24.1, R25.1, R67.1, SD1.4 (VDD), U2.2 (3V3), U6.4 (V3), U6.16 (VCC)
BAT+: J1.P$1, U8.P$5 (5_D), U8.P$6 (6_D), U8.P$7 (7_D), U8.P$8 (8_D)
D+: J3.A6 (DP1), J3.B6 (DP2), R9.1
D-: J3.A7 (DN1), J3.B7 (DN2), R8.1
DCLK: C17.2, JP1.P$11 (CLK), R26.2
ESP32_RESET: C11.1, K4.2, R5.1, R18.2, U2.3 (EN)
GND: C1.1, C2.2, C3.2, C4.1, C5.2, C6.1, C7.1, C8.1, C9.1, C10.1, C11.2, C12.1, C13.2, C14.2, C15.1, C16.2, C17.1, C18.1, C19.1, C20.2, C21.1, C23.1, C24.2, C25.2, C26.2, C29.1, C31.1, C32.1, C42.1, C43.1, C54.1, J1.P$2, J1.P$3, J1.P$4, J2.4, J2.SS1, J2.SS2, J3.A1 (GND), J3.A12 (GND), J3.B1 (GND), J3.B12 (GND), J3.P$6, J3.P$7, J3.P$8, J3.P$9, J4.1, J5.P$3, J5.P$4, J6.1, J6.4, J6.6, J6.10, J6.13 (11), J6.14 (12), J10.4, J10.SS1, J10.SS2, JP1.P$5 (GND2), JP1.P$12 (GND4), JP1.P$18 (B2), JP1.P$19 (B1), JP1.P$20 (B0), JP1.P$27 (G1), JP1.P$28 (G0), JP1.P$34 (R2), JP1.P$35 (R1), JP1.P$36 (R0), JP1.P$38 (GND3), JP1.P$41 (GND5), JP1.P$42 (GND6), K1.1, K4.1, LED1.-, Q5.2 (E), R13.1, R14.2, R15.1, R21.2, R29.2, R31.1, R58.1, SD1.6 (VSS), SD1.G1, SD1.G2, SD1.G3, SD1.G4, U1.2 (GND), U2.1 (GND1), U2.40 (GND2), U2.41 (GND3), U2.42 (GND4), U2.43 (GND5), U2.44 (GND6), U2.45 (GND7), U2.46 (GND8), U2.47 (GND9), U2.48 (GND10), U2.49 (GND11), U4.2 (2-GND), U6.1 (GND), U11.7 (GND)
I2S_BCLK: R19.1, U11.3 (BCLK)
I2S_CTRL: R22.1, U11.1 (CTRL)
I2S_SDIN: R4.1, U11.4 (SDATA)
INT: J6.9
IO0_BOOT_CLK: K1.2, R26.1, U2.27 (IO0)
IO1_B7: JP1.P$13 (B7), U2.39 (IO1)
IO2_LCD_BL_CTR: R11.2, U2.38 (IO2), U4.4 (4-EN)
IO3_B4: JP1.P$16 (B4), U2.15 (IO3)
IO4_G7: JP1.P$21 (G7), U2.4 (IO4)
IO5_G2: JP1.P$26 (G2), U2.5 (IO5)
IO6_G3: JP1.P$25 (G3), U2.6 (IO6)
IO7_G4: JP1.P$24 (G4), U2.7 (IO7)
IO8_B3: JP1.P$17 (B3), U2.12 (IO8)
IO9_B6: JP1.P$14 (B6), U2.17 (IO9)
IO10_TF_CS: R67.2, SD1.2 (CS), U2.18 (IO10)
IO11_TF_SPI_MOSI/TP_DIN: R23.2, SD1.3 (DI), U2.19 (IO11)
IO12_TF_CLK/TP_CLK: SD1.5 (SCLK), U2.20 (IO12)
IO13_TF_SPI_MISO/TP_OUT: R24.2, SD1.7 (DO), U2.21 (IO13)
IO14_R7: JP1.P$29 (R7), U2.22 (IO14)
IO15_G5: JP1.P$23 (G5), U2.8 (IO15)
IO16_G6: JP1.P$22 (G6), U2.9 (IO16)
IO17_I2S_SDIN: R4.2, U2.10 (IO17)
IO18_I2S_LRCLK: R12.2, U2.11 (IO18)
IO19_I2C_SDA: J6.5, R1.1, U2.13 (IO19)
IO20_I2C_SCL: J6.3, R7.1, U2.14 (IO20)
IO21_R6: JP1.P$30 (R6), U2.23 (IO21)
IO38_D: J2.1, J4.4, U2.31 (IO38)
IO39_HSYNC: JP1.P$9 (HSYNC), U2.32 (IO39)
IO40_DE: JP1.P$7 (DE), U2.33 (IO40)
IO41_VSYNC: JP1.P$8 (VSYNC), U2.34 (IO41)
IO42-I2S_BCLK: R19.2, U2.35 (IO42)
IO45_R3: JP1.P$33 (R3), R31.2, U2.26 (IO45)
IO46_B5: JP1.P$15 (B5), U2.16 (IO46)
IO47_R5: JP1.P$31 (R5), U2.24 (IO47)
IO48_R4: JP1.P$32 (R4), U2.25 (IO48)
LCD_LEDA: C19.2, C21.2, D6.2 (-), JP1.P$39 (LEDA), U4.5 (5-OV)
LCD_LEDK: JP1.P$40 (LEDK), R29.1, U4.3 (3-FB)
LRCLK: R12.1, U11.2 (LRCLK)
unnamed: LED1.+, R3.1
unnamed: C27.2, U11.5 (VON)
unnamed: C14.1, C28.1, J5.P$2
unnamed: JP1.P$10 (DISP), R25.2
unnamed: C28.2, U11.8 (VOP)
unnamed: J3.A5 (CC1), R13.2
unnamed: L4.1, U1.3 (SW)
unnamed: C16.1, C27.1, J5.P$1
unnamed: D6.1 (+), L5.2, U4.1 (1-SW)
unnamed: J3.B5 (CC2), R14.1
unnamed: R20.2, R21.1, U1.5 (FB)
unnamed: Q5.1 (B), R11.1, R58.2
unnamed: Q5.3 (C), Q30.1 (G), R172.2
unnamed: R72.2, U6.2 (TXD)
unnamed: R71.2, U6.3 (RXD)
unnamed: R16.2, SD1.1 (DATA2)
unnamed: R17.2, SD1.8 (DATA1)
TP_RST: J6.7, R5.2
TP_X+: JP1.P$4 (XR)
TP_X-: JP1.P$2 (XL)
TP_Y+: JP1.P$3 (YD)
TP_Y-: JP1.P$1 (YU)
UART0_RXD0: J10.1, R72.1, U2.36 (RXD0)
UART0_TXD0: J10.2, R71.1, U2.37 (TXD0)
USB_D+: R9.2, U6.5 (UD+)
USB_D-: R8.2, U6.6 (UD-)
VBUS: D3.1 (+), J3.A4 (VBUS), J3.A9 (VBUS), J3.B4 (VBUS), J3.B9 (VBUS), R15.2, U8.P$4 (4_G)
VDD: C24.1, C25.1, R10.2, R45.2, U11.6 (VDD)
VIN: C6.2, C42.2, D3.2 (-), Q30.2 (S), R45.1, R172.1, U1.1 (EN), U1.4 (VIN), U8.P$1 (1_S), U8.P$2 (2_S), U8.P$3 (3_S)
VIN2: C18.2, C43.2, L5.1, Q30.3 (D), U4.6 (6-VIN)

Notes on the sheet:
Vout=0.6*(R20/R21 +1)=3.3V
系统3.3V电源
UART0接口
主控 ESP32-S3-WROOM-1-N4R8
USB type-c座子
电池及控制电路
IO0: 低电平：下载启动 高电平：SPI启动
EN: 高电平：芯片使能； 低电平：芯片关闭。
USB转串口
IIS 功放:NS4168
TF Card
BOOT
RESET
POWER LED
LCD+TP 接口
电容屏TP
Vout=0.6*(1+RU/RN)
D接口

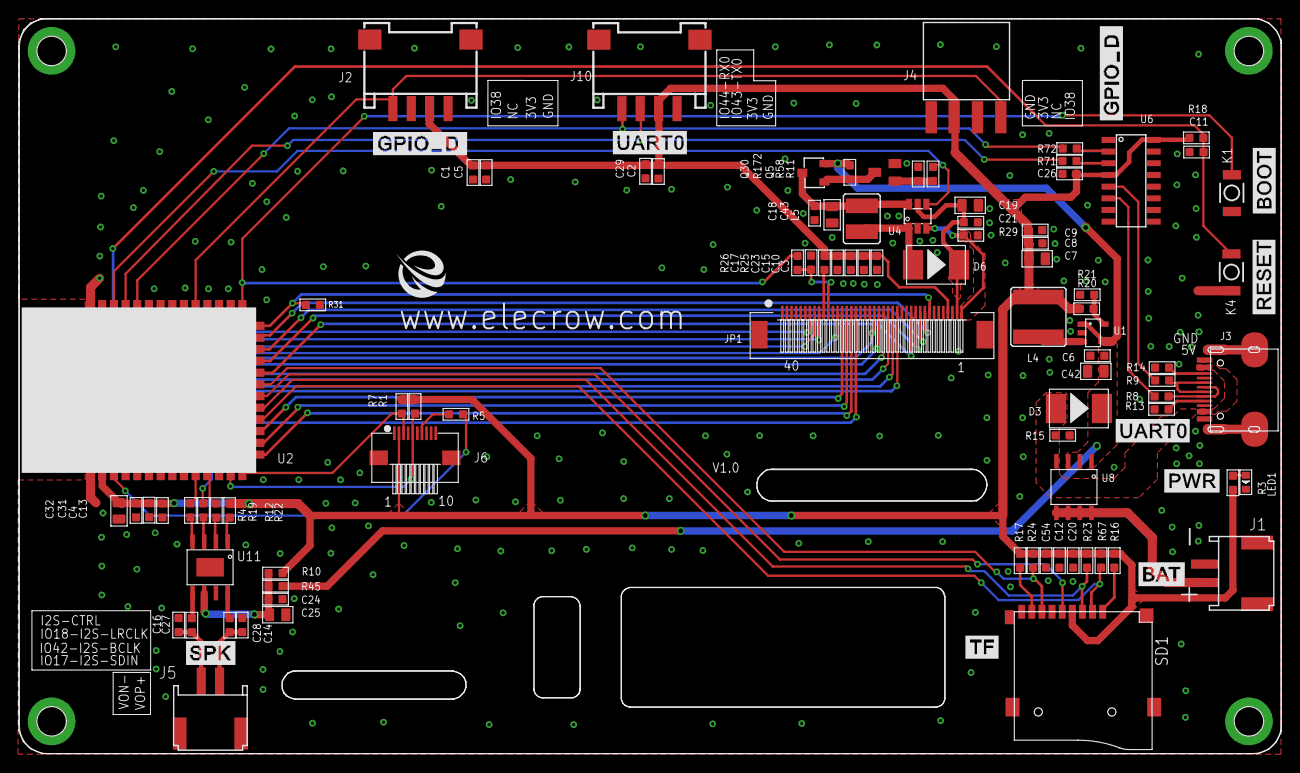
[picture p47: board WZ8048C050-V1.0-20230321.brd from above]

Board: 2 copper layers, 137.3 x 79.9 mm, 92 parts (1 on the bottom side), 70 nets.

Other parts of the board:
U$30: ELECROW-NEW
U$33: 5.0底框
U$41: 5.0板框

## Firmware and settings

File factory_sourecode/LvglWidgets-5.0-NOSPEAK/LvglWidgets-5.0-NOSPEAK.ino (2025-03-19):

#include <lvgl.h>
#include <demos/lv_demos.h>
#include <examples/lv_examples.h>

#include <Wire.h>
#include <SPI.h>
#include <SD.h>
#include <FS.h>
#include <Adafruit_SSD1306.h> 
#include <Adafruit_GFX.h>
#define oled_sda 19 
#define oled_scl 20
#define OLED_RESET     -1 

//新建iic对象以及显示屏对象
TwoWire I2Cone = TwoWire(0);
Adafruit_SSD1306 display = Adafruit_SSD1306(128, 64, &I2Cone,OLED_RESET);
/*******************************************************************************
 ******************************************************************************/
#define TFT_BL 2
#define LGFX_USE_V1
#include <LovyanGFX.hpp>
#include <lgfx/v1/platforms/esp32s3/Panel_RGB.hpp>
#include <lgfx/v1/platforms/esp32s3/Bus_RGB.hpp>
class LGFX : public lgfx::LGFX_Device
{
public:

  lgfx::Bus_RGB     _bus_instance;
  lgfx::Panel_RGB   _panel_instance;

  LGFX(void)
  {


    {
      auto cfg = _bus_instance.config();
      cfg.panel = &_panel_instance;
      
      cfg.pin_d0  = GPIO_NUM_8; // B0
      cfg.pin_d1  = GPIO_NUM_3;  // B1
      cfg.pin_d2  = GPIO_NUM_46;  // B2
      cfg.pin_d3  = GPIO_NUM_9;  // B3
      cfg.pin_d4  = GPIO_NUM_1;  // B4
      
      cfg.pin_d5  = GPIO_NUM_5;  // G0
      cfg.pin_d6  = GPIO_NUM_6; // G1
      cfg.pin_d7  = GPIO_NUM_7;  // G2
      cfg.pin_d8  = GPIO_NUM_15;  // G3
      cfg.pin_d9  = GPIO_NUM_16; // G4
      cfg.pin_d10 = GPIO_NUM_4;  // G5
      
      cfg.pin_d11 = GPIO_NUM_45; // R0
      cfg.pin_d12 = GPIO_NUM_48; // R1
      cfg.pin_d13 = GPIO_NUM_47; // R2
      cfg.pin_d14 = GPIO_NUM_21; // R3
      cfg.pin_d15 = GPIO_NUM_14; // R4

      cfg.pin_henable = GPIO_NUM_40;
      cfg.pin_vsync   = GPIO_NUM_41;
      cfg.pin_hsync   = GPIO_NUM_39;
      cfg.pin_pclk    = GPIO_NUM_0;
      cfg.freq_write  = 15000000;

      cfg.hsync_polarity    = 0;
      cfg.hsync_front_porch = 8;
      cfg.hsync_pulse_width = 4;
      cfg.hsync_back_porch  = 43;
      
      cfg.vsync_polarity    = 0;
      cfg.vsync_front_porch = 8;
      cfg.vsync_pulse_width = 4;
      cfg.vsync_back_porch  = 12;

      cfg.pclk_active_neg   = 1;
      cfg.de_idle_high      = 0;
      cfg.pclk_idle_high    = 0;

      _bus_instance.config(cfg);
    }
            {
      auto cfg = _panel_instance.config();
      cfg.memory_width  = 800;
      cfg.memory_height = 480;
      cfg.panel_width  = 800;
      cfg.panel_height = 480;
      cfg.offset_x = 0;
      cfg.offset_y = 0;
      _panel_instance.config(cfg);
    }
    _panel_instance.setBus(&_bus_instance);
    setPanel(&_panel_instance);

  }
};


LGFX lcd;
/*******************************************************************************
   End of Arduino_GFX setting
 ******************************************************************************/
#include <EEPROM.h>
String e_flag="B";  //如果想要修改已保存的WIFI信息，改下这个字母就可以
#include <WiFi.h>
#include <Ticker.h>          //Call the ticker. H Library
Ticker ticker1;
//#include "WiFiMulti.h"
//WiFiMulti wifiMulti;
#include "BLEDevice.h"              //BLE驱动库
#include "BLEServer.h"              //BLE蓝牙服务器库
#include "BLEUtils.h"               //BLE实用程序库
#include "BLE2902.h"                //特征添加描述符库
#include <BLECharacteristic.h>      //BLE特征函数库
BLEAdvertising* pAdvertising = NULL;
BLEServer* pServer = NULL;
BLEService *pService = NULL;
BLECharacteristic* pCharacteristic = NULL;
#define bleServerName "Wizee-Series-5.0"  //BLE服务器的名称
#define SERVICE_UUID "6479571c-2e6d-4b34-abe9-c35116712345"  //服务的UUID
#define CHARACTERISTIC_UUID "826f072d-f87c-4ae6-a416-6ffdcaa02d73"
bool connected_state = false;   //创建设备连接标识符

class MyServerCallbacks: public BLEServerCallbacks  //创建连接和断开调用类
{
    void onConnect(BLEServer *pServer)//开始连接函数
    {
      connected_state = true;   //设备正确连接
    }
    void onDisconnect(BLEServer *pServer)//断开连接函数
    {
      connected_state = false;  //设备连接错误
    }

};

char CloseData;
int NO_Test_Flag = 0;
int Test_Flag = 0;
int Close_Flag = 0;

#define SERIAL_BAUD 9600
HardwareSerial cardSerial(1);//声明串口1

const char *ssid = "elecrow888"; //你的网络名称
const char *password = "elecrow2014"; //你的网络密码
char buf[100] = {};
int bufindex = 0;
int wifi_close_flag = 0;
char *info[100] = {};
int wifi_flag = 0;
int i = 0;
int home_flag = 0;
int touch_flag = 0;

//5.0
#define SD_MOSI 11
#define SD_MISO 13
#define SD_SCK 12
#define SD_CS 10
unsigned long previousBlinkTime;
int blinkInterval = 15000; //LED闪烁时间间隔
#define I2S_DOUT      17
#define I2S_BCLK      42
#define I2S_LRC       18
#define BUTTON_PIN    38

//UI
#include "ui.h"
static int first_flag = 0;
extern int zero_clean;
extern int goto_widget_flag;
extern int bar_flag;
extern lv_obj_t * ui_MENU;
extern lv_obj_t * ui_TOUCH;
extern lv_obj_t * ui_JIAOZHUN;
extern lv_obj_t * ui_Label2;
static lv_obj_t * ui_Label;//TOUCH界面label
static lv_obj_t * ui_Label3;//TOUCH界面label3
static lv_obj_t * ui_Labe2;//Menu界面进度条label
static lv_obj_t * bar;//Menu界面进度条
SPIClass& spi = SPI;
uint16_t touchCalibration_x0 = 300, touchCalibration_x1 = 3600, touchCalibration_y0 = 300, touchCalibration_y1 = 3600;
uint8_t  touchCalibration_rotate = 1, touchCalibration_invert_x = 2, touchCalibration_invert_y = 0;
static int val = 100;

/*******************************************************************************
   Please config the touch panel in touch.h
 ******************************************************************************/
#include "touch.h"
#include "Audio.h"
Audio audio;
String music_url;
int music_id = 1818615872;
//#include "GxFT5436.h"
//GxFT5436 tp =GxFT5436(37,38,3);
/* Change to your screen resolution */
static uint32_t screenWidth;
static uint32_t screenHeight;
static lv_disp_draw_buf_t draw_buf;
static lv_color_t disp_draw_buf[800 * 480 / 10];
//static lv_color_t disp_draw_buf;
static lv_disp_drv_t disp_drv;

/* Display flushing */
void my_disp_flush(lv_disp_drv_t *disp, const lv_area_t *area, lv_color_t *color_p)
{

  uint32_t w = (area->x2 - area->x1 + 1);
  uint32_t h = (area->y2 - area->y1 + 1);
  

  //lcd.fillScreen(TFT_WHITE);
#if (LV_COLOR_16_SWAP != 0)
 lcd.pushImageDMA(area->x1, area->y1, w, h,(lgfx::rgb565_t*)&color_p->full);
#else
  lcd.pushImageDMA(area->x1, area->y1, w, h,(lgfx::rgb565_t*)&color_p->full);//
#endif

  lv_disp_flush_ready(disp);

}

void my_touchpad_read(lv_indev_drv_t *indev_driver, lv_indev_data_t *data)
{
  if (touch_has_signal())
  {
    if (touch_touched())
    {
      data->state = LV_INDEV_STATE_PR;

      /*Set the coordinates*/
      data->point.x = touch_last_x;
      data->point.y = touch_last_y;
      Serial.print( "Data x :" );
      Serial.println( touch_last_x );

      Serial.print( "Data y :" );
      Serial.println( touch_last_y );
    }
    else if (touch_released())
    {
      data->state = LV_INDEV_STATE_REL;
    }
  }
  else
  {
    data->state = LV_INDEV_STATE_REL;
  }
  delay(15);
}

unsigned char buffer[256]; // buffer array for data recieve over serial port
int count_1 = 0;   // counter for buffer array
void clearBufferArray()              // function to clear buffer array
{
  for (int i = 0; i < count_1; i++)
  {
    buffer[i] = 0; // clear all index of array with command NULL
  }
}

uint16_t calData[5] = { 190, 3679, 382, 3335, 0 };
void callback1()  //Callback function
{
  if (bar_flag == 6)
  {
    if (val > 1)
    {
      val--;
      lv_bar_set_value(bar, val, LV_ANIM_OFF);
      lv_label_set_text_fmt(ui_Labe2, "%d %%", val);
    }
    else
    {
      lv_obj_clear_flag(ui_touch, LV_OBJ_FLAG_CLICKABLE);
      lv_label_set_text(ui_Labe2, "Loading");
      delay(150);
      val = 100;
      bar_flag = 0; //停止进度条标志
      goto_widget_flag = 1; //进入widget标志

    }
  }
}

//读取或保存信息；
void save_or_read_wifi(void){
  EEPROM.begin(1024);
  if(get_string(1,0) == e_flag){ //如果第0位字符为“M”，则表示已储存WIFI信息
      Serial.println("已储存信息");
  }
  else{
    Serial.println("未储存有WIFI信息,将储存wifi信息");
    //保存信息
    set_string(1,0,e_flag,0); //录入"N"字符
    Serial.println("完成储存");
    Serial.println("即将重启");
    ESP.restart();
  }
  EEPROM.end();
}

//用EEPROM的a位保存字符串的长度，字符串的从EEPROM的b位开始保存，str为要保存的字符串，s为是否保存字符串长度
void set_string(int a,int b,String str,int s)
{
  if(s)EEPROM.write(a,str.length()); //EEPROM第a位，写入str字符串的长度
  //通过一个for循环，把str所有数据，逐个保存在EEPROM
  for(int i = 0; i < str.length(); i++){
    EEPROM.write(b + i, str[i]);
  }
  EEPROM.commit();  //执行保存EEPROM

}

//获取指定EEPROM位置的字符串，a是字符串长度，b是起始位，从EEPROM的b位开始读取
String get_string(int a,int b){
  String data="";
  //通过一个for循环，从EEPROM中逐个取出每一位的值，并连接起来
  for(int i=0; i<a; i++){
    data += char(EEPROM.read(b+i));
  }
  return data;
}

void setup()
{
  //  pinMode(TFT_BL, OUTPUT);
  //  digitalWrite(TFT_BL, LOW);
  Serial.begin(9600);
  Serial.println("LVGL Widgets Demo");

  //IO口引脚
  pinMode(38, OUTPUT);
  digitalWrite(38, LOW);
  pinMode(17, OUTPUT);
  digitalWrite(17, LOW);
  pinMode(18, OUTPUT);
  digitalWrite(18, LOW);
  pinMode(42, OUTPUT);
  digitalWrite(42, LOW);
    // EEPROM.begin(1024);
    // if(get_string(1,0) == e_flag){ //如果第0位字符为“M”，则表示已储存WIFI信息
    //     Serial.println("已储存信息");
    //     pinMode(SD_CS, OUTPUT);      digitalWrite(SD_CS, HIGH);
    //     SPI.begin(SD_SCK, SD_MISO, SD_MOSI);
    //     SPI.setFrequency(1000000);
    //     SD.begin(SD_CS);
    //     audio.setPinout(I2S_BCLK, I2S_LRC, I2S_DOUT);
    //     audio.setVolume(15); // 0...21//volume adjustment
    //     audio.connecttoFS(SD, "/123.mp3");
    //     while (1)
    //     {
    //       unsigned long currentMillis = millis();
    //       //检查是否到达时间间隔
    //       if (currentMillis - previousBlinkTime >= blinkInterval) {    //如果时间间隔达到了
    //         audio.stopSong();
    //         break;
    //       }
    //       else if (currentMillis - previousBlinkTime <= 0)
    //       { // 如果millis时间溢出
    //         previousBlinkTime = currentMillis;
    //       }
    //       audio.loop();
    //     }
    // }
    // else{
    //   Serial.println("未储存有WIFI信息,将储存wifi信息");
    //   //保存信息
    //   set_string(1,0,e_flag,0); //录入"N"字符
    //   Serial.println("完成储存");
    //   Serial.println("即将重启");
    //   ESP.restart();
    // }
    // EEPROM.end();

  //BLE
  BLEDevice::init(bleServerName);  //创建BLE并设置名称
  pServer = BLEDevice::createServer();  //创建BLE服务器
  pServer->setCallbacks(new MyServerCallbacks());  //设置连接和断开调用类
  pService = pServer->createService(SERVICE_UUID); //创建BLE服务

  pCharacteristic = pService->createCharacteristic(  //Create ble feature（Characterristic_UUID）
                      CHARACTERISTIC_UUID,
                      BLECharacteristic::PROPERTY_READ | BLECharacteristic::PROPERTY_WRITE | BLECharacteristic::PROPERTY_NOTIFY);
  pCharacteristic->setValue("ELECROW");
  //开始广播
  pAdvertising = BLEDevice::getAdvertising();  //A bleadvertising class pointer padvertising is defined, which points to bledevice:: getadvertising()
  pAdvertising->addServiceUUID(SERVICE_UUID);


  // Init Display
  lcd.begin();
  lcd.fillScreen(TFT_BLACK);
  lcd.setTextSize(2);
  delay(200);

  //  lcd.fillScreen(TFT_REDRED);
  //  delay(500);
  //  lcd.fillScreen(TFT_REDGREEN);
  //  delay(500);
  //  lcd.fillScreen(TFT_REDBLUE);
  //  delay(500);
  //  lcd.fillScreen(TFT_BLACK);
  //  delay(500);

  lv_init();

  delay(100);
  touch_init();

  screenWidth = lcd.width();
  screenHeight = lcd.height();

  lv_disp_draw_buf_init(&draw_buf, disp_draw_buf, NULL, screenWidth * screenHeight / 10);
  //  lv_disp_draw_buf_init(&draw_buf, disp_draw_buf, NULL, 480 * 272 / 10);
  /* Initialize the display */
  lv_disp_drv_init(&disp_drv);
  /* Change the following line to your display resolution */
  disp_drv.hor_res = screenWidth;
  disp_drv.ver_res = screenHeight;
  disp_drv.flush_cb = my_disp_flush;
  disp_drv.draw_buf = &draw_buf;
  lv_disp_drv_register(&disp_drv);

  /* Initialize the (dummy) input device driver */
  static lv_indev_drv_t indev_drv;
  lv_indev_drv_init(&indev_drv);
  indev_drv.type = LV_INDEV_TYPE_POINTER;
  indev_drv.read_cb = my_touchpad_read;
  lv_indev_drv_register(&indev_drv);
#ifdef TFT_BL
  pinMode(TFT_BL, OUTPUT);
  digitalWrite(TFT_BL, HIGH);
#endif
  ui_init();//开机UI界面
  while (1)
  {
    if (goto_widget_flag == 1)//进入widget
    {
      if (ticker1.active() == true)
      {
        ticker1.detach();
      }
      goto_widget_flag = 0;
      delay(300);
      break;
    }

    if (goto_widget_flag == 3)//进入触摸界面，先把进度条线程关闭
    {
      bar_flag = 0; //停止进度条标志
      if (ticker1.active() == true)
      {
        ticker1.detach();
      }
      if (first_flag == 0 || first_flag == 1)
      {
        label_xy();
        first_flag = 2;
      }
      if (zero_clean == 1)
      {
        touch_last_x = 0;
        touch_last_y = 0;
        zero_clean = 0;
      }
      lv_label_set_text(ui_Label, "Touch Adjust:");
      lv_label_set_text_fmt(ui_Label3, "%d  %d", touch_last_x, touch_last_y); //显示触摸信息
    }

    if (goto_widget_flag == 4)//触摸界面返回到Menu界面,使进度条清零重启
    {
      val = 100;
      delay(100);
      ticker1.attach_ms(35, callback1);//每20ms调用callback1
      goto_widget_flag = 0;
    }

    if (goto_widget_flag == 5) //触发校准信号
    {
      lv_scr_load_anim(ui_touch_calibrate, LV_SCR_LOAD_ANIM_NONE, 0, 0, false);
      lv_timer_handler();
      lv_timer_handler();
      delay(100);
      touch_calibrate();//触摸校准
      lv_scr_load_anim(ui_TOUCH, LV_SCR_LOAD_ANIM_NONE, 0, 0, false);
      lv_timer_handler();
      delay(100);
      goto_widget_flag = 3; //进入触摸界面标志
      touch_last_x = 0;
      touch_last_y = 0;
    }

    if (bar_flag == 6)//刚开机进入Menu界面时运行进度条一次，之后就不再运行
    {
      if (first_flag == 0)
      {
        lv_example_bar();
        ticker1.attach_ms(35, callback1);//每20ms调用callback1
        first_flag = 1;
      }
    }

    lv_timer_handler();
  }


  lcd.fillScreen(TFT_BLACK);
  lv_demo_widgets();//主UI界面
  Serial.println( "Setup done" );

}

void loop()
{
  while (NO_Test_Flag == 0)
  {
    lv_timer_handler();
    delay(5);
    CloseData = Serial.read();
    if (CloseData == 'b')  //Exit
    {
      NO_Test_Flag = 1;
      Test_Flag = 1;
      lcd.fillScreen(TFT_BLACK);
      Serial.println("进入测试程序");
      WiFi.disconnect();
      break;
    }
    
  }

  //*********************************测试程序***************************************
  //*********************************测试程序***************************************
  //*********************************测试程序***************************************
  while (Test_Flag == 1)
  {
    Ce_shi();
  }
  ESP.restart();//软件复位
}

//触摸Label控件
void label_xy()
{
  ui_Label = lv_label_create(ui_TOUCH);
  lv_obj_enable_style_refresh(true);
  lv_obj_set_width(ui_Label, LV_SIZE_CONTENT);   /// 1
  lv_obj_set_height(ui_Label, LV_SIZE_CONTENT);    /// 1
  lv_obj_set_x(ui_Label, -55);
  lv_obj_set_y(ui_Label, -40);
  lv_obj_set_align(ui_Label, LV_ALIGN_CENTER);
  lv_obj_set_style_text_color(ui_Label, lv_color_hex(0xFF0000), LV_PART_MAIN | LV_STATE_DEFAULT);
  lv_obj_set_style_text_opa(ui_Label, 255, LV_PART_MAIN | LV_STATE_DEFAULT);
  lv_obj_set_style_text_font(ui_Label, &lv_font_montserrat_24, LV_PART_MAIN | LV_STATE_DEFAULT);

  ui_Label3 = lv_label_create(ui_TOUCH);
  lv_obj_enable_style_refresh(true);
  lv_obj_set_width(ui_Label3, LV_SIZE_CONTENT);   /// 1
  lv_obj_set_height(ui_Label3, LV_SIZE_CONTENT);    /// 1
  lv_obj_set_x(ui_Label3, 85);
  lv_obj_set_y(ui_Label3, -40);
  lv_obj_set_align(ui_Label3, LV_ALIGN_CENTER);
  lv_obj_set_style_text_color(ui_Label3, lv_color_hex(0x00FF00), LV_PART_MAIN | LV_STATE_DEFAULT);
  lv_obj_set_style_text_opa(ui_Label3, 255, LV_PART_MAIN | LV_STATE_DEFAULT);
  lv_obj_set_style_text_font(ui_Label3, &lv_font_montserrat_24, LV_PART_MAIN | LV_STATE_DEFAULT);

}


//进度条控件
void lv_example_bar(void)
{
  //////////////////////////////
  bar = lv_bar_create(ui_MENU);
  lv_bar_set_value(bar, 0, LV_ANIM_OFF);
  lv_obj_set_width(bar, 480);
  lv_obj_set_height(bar, 25);
  lv_obj_set_x(bar, 0);
  lv_obj_set_y(bar, 175);
  lv_obj_set_align(bar, LV_ALIGN_CENTER);
  lv_obj_set_style_bg_img_src(bar, &ui_img_bar_800_01_png, LV_PART_MAIN | LV_STATE_DEFAULT);

  lv_obj_set_style_bg_img_src(bar, &ui_img_bar_800_02_png, LV_PART_INDICATOR | LV_STATE_DEFAULT);
  lv_obj_set_style_outline_color(bar, lv_color_hex(0x2D8812), LV_PART_INDICATOR | LV_STATE_DEFAULT);
  lv_obj_set_style_outline_opa(bar, 255, LV_PART_INDICATOR | LV_STATE_DEFAULT);
  //////////////////////
  ui_Labe2 = lv_label_create(bar);//创建标签
  lv_obj_set_style_text_color(ui_Labe2, lv_color_hex(0x09BEFB), LV_STATE_DEFAULT);
  lv_label_set_text(ui_Labe2, "0%");
  lv_obj_center(ui_Labe2);
}
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

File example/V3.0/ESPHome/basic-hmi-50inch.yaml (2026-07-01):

esphome:
  name: basic-hmi-50inch                                     # Node name for the ESPHome device
  friendly_name: Basic_HMI_5.0inch                           # Human-readable name for Home Assistant
  platformio_options:                                        # Custom PlatformIO build configuration
    build_flags: 
      - "-DBOARD_HAS_PSRAM"                                  # Enable PSRAM support in compilation
    board_build.esp-idf.memory_type: qio_opi                 # Set memory type for ESP-IDF framework
    board_build.flash_mode: dio                              # Set SPI flash access mode to DIO

  on_boot:                                                   # Actions to execute during boot phase
    priority: 600                                            # High priority to run before most components
    then: 
      - lambda: |- 
          uint8_t addr = 0x18;                               // PCA9557 I2C expander slave address
          
          uint8_t config[2] = {0x03, 0x00};                  // 1. Set all PCA9557 pins as outputs
          id(bus_a).write(addr, config, 2);                  // Write configuration via I2C bus
          
          uint8_t output_low[2] = {0x01, 0x00};              // 2. IO0=LOW, IO1=LOW (Hard reset GT911)
          id(bus_a).write(addr, output_low, 2);              // Apply low signals to reset pins
          
          delay(20);                                         // 3. Hold reset state for 20 milliseconds
          
          uint8_t output_high[2] = {0x01, 0x01};             // 4. IO0=HIGH (Release GT911 reset sequence)
          id(bus_a).write(addr, output_high, 2);             // Apply high signal to wake up touch IC
          
          delay(100);                                        // 5. Wait 100ms for touch IC to initialize
          
          uint8_t config_input[2] = {0x03, 0x02};            // 6. Set IO1 as input for GT911 interrupt
          id(bus_a).write(addr, config_input, 2);            // Finalize PCA9557 pin configuration

esp32:                                                       # ESP32 specific hardware configuration
  board: esp32s3box                                          # Base board model for ESP32-S3
  framework: 
    type: esp-idf                                            # Use official ESP-IDF framework, not Arduino
    sdkconfig_options: 
      CONFIG_ESP32S3_DEFAULT_CPU_FREQ_240: y                 # Set CPU frequency to max (240MHz)
      CONFIG_ESP32S3_DATA_CACHE_64KB: y                      # Allocate 64KB for data cache
      CONFIG_SPIRAM_FETCH_INSTRUCTIONS: y                    # Allow instruction fetch from SPIRAM
      CONFIG_SPIRAM_RODATA: y                                # Store read-only data in SPIRAM
      CONFIG_SPIRAM_USE: y                                   # Enable external SPIRAM globally
      CONFIG_SPIRAM_SPEED_80M: y                             # Set SPIRAM clock speed to 80MHz
      CONFIG_SPIRAM_MODE_OCT: y                              # Use Octal mode for faster RAM access
      CONFIG_ESP32S3_SPIRAM_SUPPORT: y                       # Enable ESP32-S3 specific SPIRAM support
  variant: esp32s3                                           # Specify the chip variant exactly

psram:                                                       # Physical PSRAM configuration block
  mode: octal                                                # Octal SPI mode matches board layout
  speed: 80MHz                                               # 80MHz speed matches sdkconfig options

logger:                                                      # Enable serial console logging output

api:                                                         # Enable Home Assistant native API
  encryption:
    key: "rtwa5RpA76iUnridsvbzfCTksdLVnCayR8emMERD458="      # Encryption key for secure API traffic

ota:                                                         # Over-The-Air firmware update settings
  - platform: esphome
    password: "fe7be42dce2a55366a21117adbb7800a"             # Password required for OTA updates

wifi:                                                        # Wi-Fi network connection settings
  ssid: !secret wifi_ssid                                    # Main network SSID from secrets.yaml
  password: !secret wifi_password                            # Main network password from secrets.yaml
  ap:
    ssid: "Basic-Hmi-50Inch"                                 # Fallback Access Point SSID if Wi-Fi fails
    password: "CVoV1AXZmVRl"                                 # Fallback Access Point password

captive_portal:                                              # Enable web portal when in AP mode
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

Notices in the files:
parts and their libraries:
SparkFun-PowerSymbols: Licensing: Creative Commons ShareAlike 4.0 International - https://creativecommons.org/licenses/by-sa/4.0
